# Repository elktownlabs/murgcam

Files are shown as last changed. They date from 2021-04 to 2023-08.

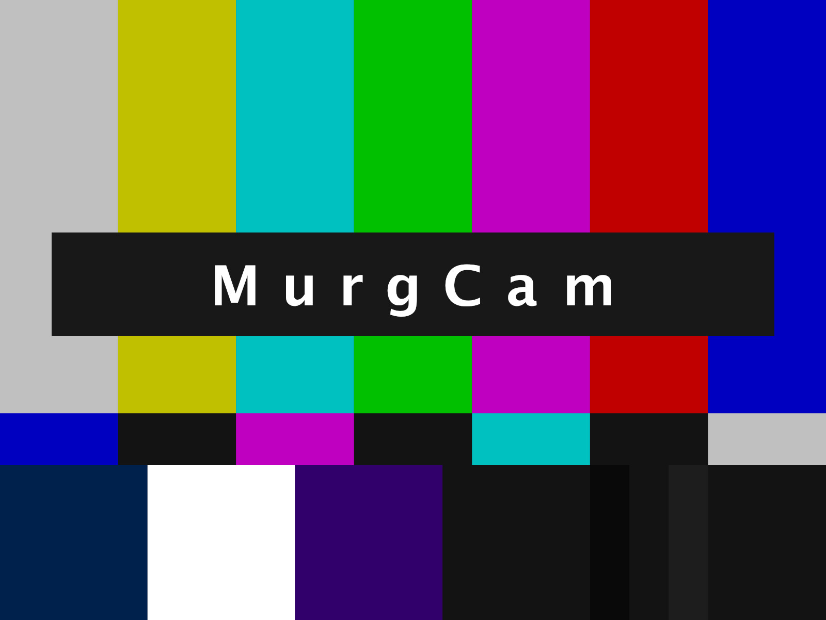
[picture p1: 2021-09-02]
web-backend/api/testcard.jpg

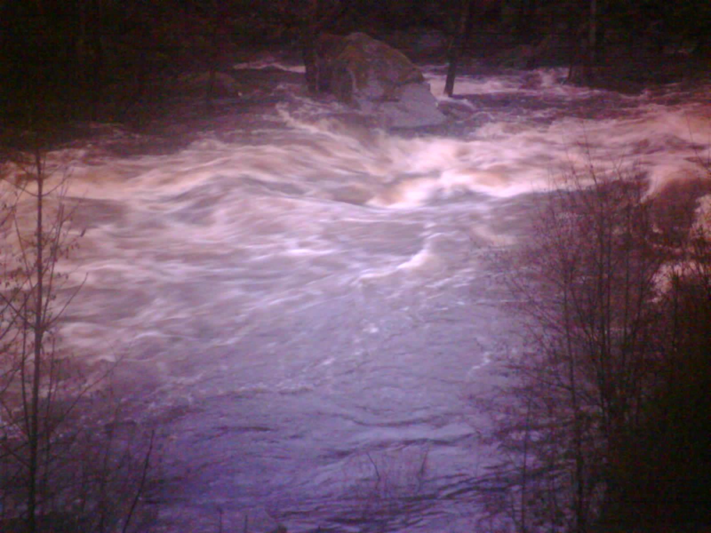
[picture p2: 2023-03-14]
web-backend/refphotos/high.jpeg

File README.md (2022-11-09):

# murgcam
Autonomous, time-based, low power still camera.

The first instance of this camera in action:
https://wwv-schwarzwald.de/die-murg/cam

## Project description
This repo documents Hard- and Software for a very low-power, battery/solar powered camera with GSM/LTE connectivity.
It is designed to operate unattended for months in an off-grid environment.
It will upload images to a server on a time-based trigger.

The intended use-case is to monitor river-waterlevels for whitewater paddlers. 
The advantage of a camera over other gauging techniques 
is, only line-of sight is needed, no access to the Water.
Being diectly at the water brings legal and mechanical challenginges that are not at play using a camera.

Full discussion of the original design decisions here:
https://elktown-labs.com/autonomouscam/

## Status
The repo just transferred from non-public to public, we try to add more documentation.
Currently, work is going on for a new hardware revision with a few improvements, most notably upgrading to a LTE capable Modem.

## Participation welcome
If you are interested in building / operating such a camera or want to contribute to it's development,
feel free to open an [issue](https://github.com/elktownlabs/murgcam/issues).

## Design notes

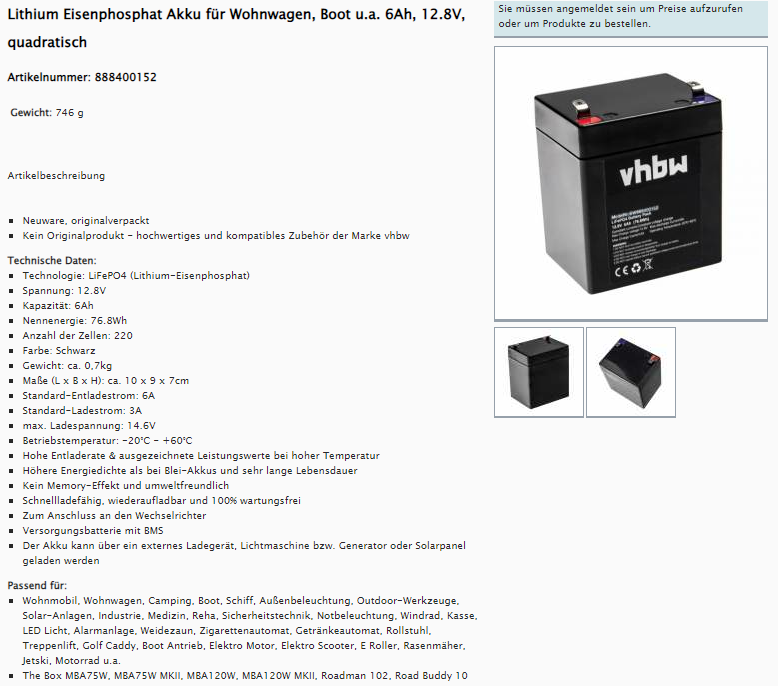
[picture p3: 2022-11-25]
cad/battery/battery_LiFePO4.png

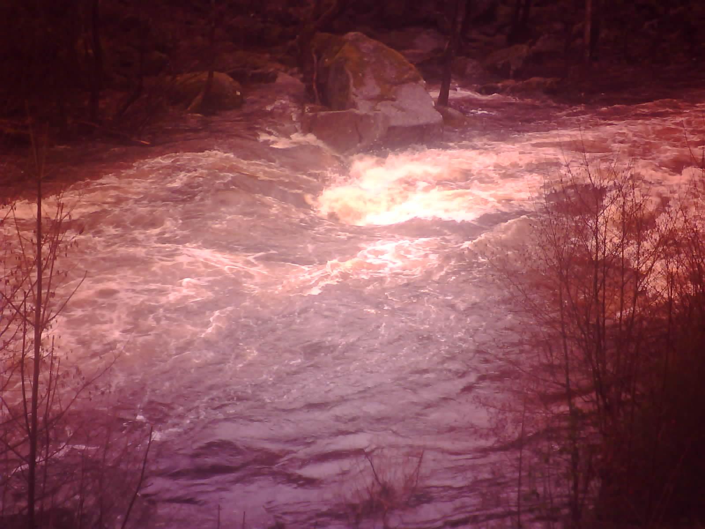
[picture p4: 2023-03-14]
web-backend/refphotos/medium.jpeg

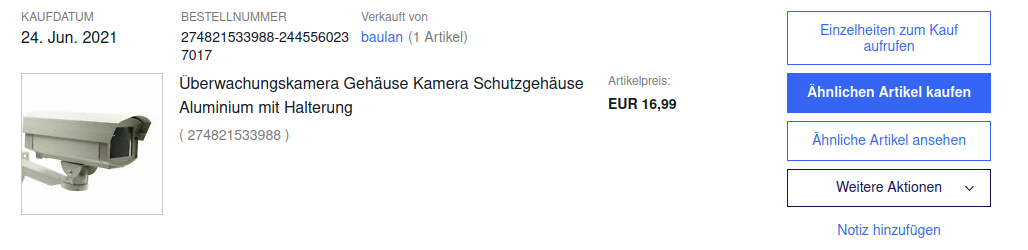
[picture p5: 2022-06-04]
cad/enclosure_narrow/cam_narrow.png

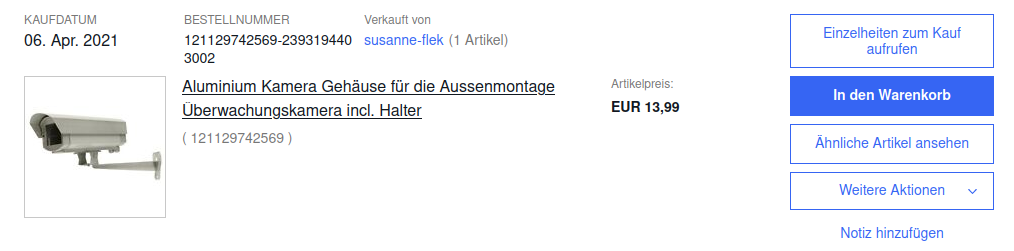
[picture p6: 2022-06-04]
cad/enclosure_wide/cam_wide.png

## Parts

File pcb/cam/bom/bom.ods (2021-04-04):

Reference | Value | Footprint
U13 | SIM800C | RF_GSM:SIMCom_SIM800C
J5 | SIM_Card | Elktown Footprints:MicroSim_6P
R20 | 51 | Resistor_SMD:R_0603_1608Metric
R21 | 51 | Resistor_SMD:R_0603_1608Metric
R22 | 51 | Resistor_SMD:R_0603_1608Metric
C43 | 100n | Capacitor_SMD:C_0603_1608Metric
C42 | 22p | Capacitor_SMD:C_0603_1608Metric
J6 | Conn_Coaxial | Connector_Coaxial:U.FL_Hirose_U.FL-R-SMT-1_Vertical
R23 | 10k | Resistor_SMD:R_0603_1608Metric
R24 | 39k | Resistor_SMD:R_0603_1608Metric
R25 | 10k | Resistor_SMD:R_0603_1608Metric
R26 | 39k | Resistor_SMD:R_0603_1608Metric
C46 | 15p | Capacitor_SMD:C_0603_1608Metric
R27 | 51 | Resistor_SMD:R_0603_1608Metric
U3 | XC6206-12 | Package_TO_SOT_SMD:SOT-23
U4 | XC6206-28 | Package_TO_SOT_SMD:SOT-23
C9 | 10u | Capacitor_SMD:C_0805_2012Metric
C16 | 10u | Capacitor_SMD:C_0805_2012Metric
C17 | 10u | Capacitor_SMD:C_0805_2012Metric
C45 | 100n | Capacitor_SMD:C_0603_1608Metric
R13 | 10k | Resistor_SMD:R_0603_1608Metric
R11 | 4.7k | Resistor_SMD:R_0603_1608Metric
J2 | Power In | Connector_JST:JST_XH_B2B-XH-A_1x02_P2.50mm_Vertical
D1 | SMAJ15CA | Diode_SMD:D_SMA
C18 | 22n | Capacitor_SMD:C_0603_1608Metric
TP1 | 1V2 | TestPoint:TestPoint_Loop_D2.60mm_Drill0.9mm_Beaded
TP2 | 2V8 | TestPoint:TestPoint_Loop_D2.60mm_Drill0.9mm_Beaded
U12 | SRV05-4 | Package_TO_SOT_SMD:SOT-23-6 | Not populated
C8 | 10u | Capacitor_SMD:C_0805_2012Metric
L2 | 10u, 3A | Elktown Footprints:IND_LPS3314-222MRC
C6 | 100n | Capacitor_SMD:C_0603_1608Metric
TP3 | 3V3 | TestPoint:TestPoint_Loop_D2.60mm_Drill0.9mm_Beaded
C19 | 22p | Capacitor_SMD:C_0603_1608Metric
R6 | 442k | Resistor_SMD:R_0603_1608Metric
C20 | 100n | Capacitor_SMD:C_0603_1608Metric
U1 | TPS22810 | Package_TO_SOT_SMD:SOT-23-6
U6 | INA226 | Package_SO:VSSOP-10_3x3mm_P0.5mm
R4 | 50mOhm 1% | Inductor_SMD:L_1206_3216Metric
U2 | FDC610 | Package_TO_SOT_SMD:SuperSOT-6
C23 | 100n | Capacitor_SMD:C_0603_1608Metric
J1 | Conn_Coaxial | Connector_Coaxial:U.FL_Hirose_U.FL-R-SMT-1_Vertical
C1 | open | Capacitor_SMD:C_0603_1608Metric
C2 | short | Capacitor_SMD:C_0603_1608Metric
L1 | open | Inductor_SMD:L_0603_1608Metric
Y2 | 40Mhz | Crystal:Crystal_SMD_5032-4Pin_5.0x3.2mm | Ordered AliExpress
C10 | TBD | Capacitor_SMD:C_0603_1608Metric
C13 | TBD | Capacitor_SMD:C_0603_1608Metric
C14 | 1u | Capacitor_SMD:C_0603_1608Metric
R5 | 0 | Inductor_SMD:L_0603_1608Metric
C28 | 100n | Capacitor_SMD:C_0603_1608Metric
C34 | 100n | Capacitor_SMD:C_0603_1608Metric
C37 | 100n | Capacitor_SMD:C_0603_1608Metric
R14 | 4.7k | Resistor_SMD:R_0603_1608Metric
U5 | LTC3103 | Package_SO:MSOP-10-1EP_3x3mm_P0.5mm_EP1.68x1.88mm
C11 | 1u, 25V CERAMIC | Capacitor_SMD:C_0805_2012Metric | Ordered AliExpress
R8 | 2M | Resistor_SMD:R_0603_1608Metric
R7 | 1M | Resistor_SMD:R_0603_1608Metric
C50 | 10p | Capacitor_SMD:C_0603_1608Metric
C49 | 33p | Capacitor_SMD:C_0603_1608Metric
C48 | 10u | Capacitor_SMD:C_0805_2012Metric | Ordered AliExpress
C44 | 100n | Capacitor_SMD:C_0603_1608Metric
Q1 | IRLML6402 | Package_TO_SOT_SMD:SOT-23
R9 | 10k | Resistor_SMD:R_0603_1608Metric
C38 | 100u, 10V | Capacitor_SMD:C_1206_3216Metric | Ordered AliExpress
C22 | 22u, 25V | Capacitor_SMD:C_1210_3225Metric
TP4 | 4V | TestPoint:TestPoint_Loop_D2.60mm_Drill0.9mm_Beaded | Ordered AliExpress
C32 | 10n | Capacitor_SMD:C_0603_1608Metric
R16 | 33.2k | Resistor_SMD:R_0603_1608Metric
R15 | 10k | Resistor_SMD:R_0603_1608Metric
R12 | 6.8k | Resistor_SMD:R_0603_1608Metric
C30 | 3.9n | Capacitor_SMD:C_0603_1608Metric | Use 3.3n
R10 | 47k | Resistor_SMD:R_0603_1608Metric
C27 | 100n | Capacitor_SMD:C_0603_1608Metric
U8 | MP2307 | Package_SO:SOIC-8-1EP_3.9x4.9mm_P1.27mm_EP2.514x3.2mm
L3 | 15u, 2.3A | Elktown Footprints:MSS7348-XXXMEC
C21 | 47u | Capacitor_SMD:C_1206_3216Metric | Ordered AliExpress
U10 | W25Q128JVS | Package_SO:SOIC-8_5.23x5.23mm_P1.27mm | Ordered AliExpress
R17 | 10k | Resistor_SMD:R_0603_1608Metric
U11 | LY68L6400 | Package_SO:SOIC-8_3.9x4.9mm_P1.27mm
R19 | TBD | Resistor_SMD:R_0603_1608Metric
D2 | LED_RED | LED_SMD:LED_0603_1608Metric
R18 | TBD | Resistor_SMD:R_0603_1608Metric
D3 | LED_BLUE | LED_SMD:LED_0603_1608Metric
C5 | 10u, 25V ceramic | Capacitor_SMD:C_1210_3225Metric | Schublade
C41 | 100n | Capacitor_SMD:C_0603_1608Metric
C40 | 100n | Capacitor_SMD:C_0603_1608Metric
J4 | Conn_01x24_Male | Connector_FFC-FPC:Hirose_FH12-24S-0.5SH_1x24-1MP_P0.50mm_Horizontal
R3 | open | Resistor_SMD:R_0603_1608Metric
C29 | 10u | Capacitor_SMD:C_0805_2012Metric | Ordered AliExpress
C33 | 100n | Capacitor_SMD:C_0603_1608Metric
C25 | 100n | Capacitor_SMD:C_0603_1608Metric
C26 | 100n | Capacitor_SMD:C_0603_1608Metric
C7 | TBD | Capacitor_SMD:C_0603_1608Metric
Y1 | 32.768kHz | Crystal:Crystal_SMD_SeikoEpson_MC306-4Pin_8.0x3.2mm
C12 | TBD | Capacitor_SMD:C_0603_1608Metric
C15 | 1u | Capacitor_SMD:C_0603_1608Metric
R1 | 0 | Resistor_SMD:R_0603_1608Metric
R28 | 0 | Resistor_SMD:R_0603_1608Metric
R29 | 10k | Resistor_SMD:R_0603_1608Metric
R31 | 4.7k | Resistor_SMD:R_0603_1608Metric
R30 | 4.7k | Resistor_SMD:R_0603_1608Metric
R32 | 10k | Resistor_SMD:R_0603_1608Metric
J7 | JTAG | Connector_PinHeader_1.27mm:PinHeader_2x05_P1.27mm_Vertical | Ordered AliExpress: does not fit. Need to be re-ordered
J3 | PRGR | Connector_PinHeader_1.27mm:PinHeader_2x03_P1.27mm_Vertical
C39 | 100n | Capacitor_SMD:C_0603_1608Metric
R2 | 10k | Resistor_SMD:R_0603_1608Metric
C3 | 100p | Capacitor_SMD:C_0603_1608Metric
C4 | 1u | Capacitor_SMD:C_0603_1608Metric
U7 | ESP32-S2 | Package_DFN_QFN:QFN-56-1EP_7x7mm_P0.4mm_EP5.6x5.6mm_ThermalVias | Ordered AliExpress

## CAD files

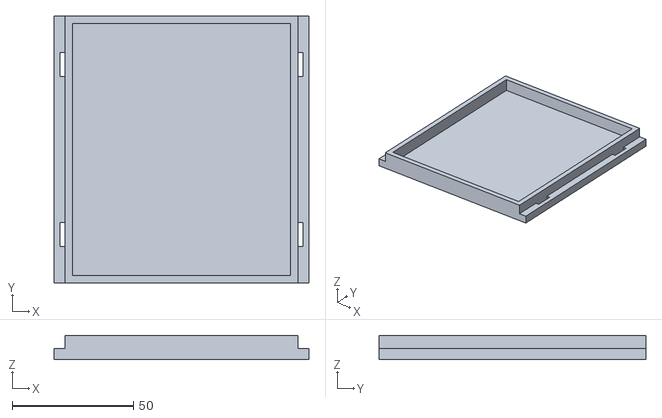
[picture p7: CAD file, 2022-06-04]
cad/enclosure_wide/base_for_battery/base.stl
105.0 x 110.0 x 10.0

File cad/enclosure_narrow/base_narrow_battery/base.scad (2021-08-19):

WIDTH = 98.0;
LENGTH = 111;
HEIGHT = 3.5;
HOLDER_HEIGHT = 1.7;
BORDER_HEIGHT = 13;
HOLDER_WIDTH = 5.5;
BORDER_WIDTH=0;
BORDER_WIDTH_FRONTBACK = 4;

union() {
    cube([WIDTH, LENGTH, HOLDER_HEIGHT]);
    translate([HOLDER_WIDTH, 0, HOLDER_HEIGHT/2])
        difference() {
            cube([WIDTH - (2*HOLDER_WIDTH), LENGTH, BORDER_HEIGHT]);
            translate([BORDER_WIDTH, BORDER_WIDTH_FRONTBACK, HEIGHT]) 
                cube([WIDTH - (2*(HOLDER_WIDTH+BORDER_WIDTH)), LENGTH-(2*BORDER_WIDTH_FRONTBACK), BORDER_HEIGHT-HEIGHT]);
        }
    translate([0, WIDTH/2+5, 0]) linear_extrude(height=HOLDER_HEIGHT) circle(r=10);
}

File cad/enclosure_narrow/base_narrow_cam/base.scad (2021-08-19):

include <bolts/BOLTS.scad>
$fn=30;

WIDTH = 98.0;
LENGTH = 75;
HEIGHT=3.5;
HOLDER_HEIGHT = 1.7;
HOLDER_WIDTH = 5.5;


BOARD_HOLE_WIDTH=55;
BOARD_HOLE_LENGTH=65;
BOARD_MOUNTING_HEIGHT=5;

module board_holder(height) {
    union() {
        difference() {
            cube([10, 10, height]);
            translate([5, 5, -0.5]) {
                cylinder(height+1, d=3.2);
                cylinder(height, d=3.4);
            }
            translate([5, 5, -0.01]) 
            scale([1.1, 1.1, 1])
                ISO4032("M3",part_mode="diff");    
        }
    }
}


union() {

    difference() {
        union() {
            cube([WIDTH, LENGTH, HOLDER_HEIGHT]);
            translate([HOLDER_WIDTH, 0, HOLDER_HEIGHT/2])
            cube([WIDTH - (2*HOLDER_WIDTH), LENGTH, HEIGHT]);
        }
        translate([(WIDTH-BOARD_HOLE_WIDTH-10)/2, 0, 0]) {
            translate([0, 0, -0.05])
            cube(10, 10, BOARD_MOUNTING_HEIGHT+HEIGHT+0.1);
            translate([BOARD_HOLE_WIDTH, 0, -0.05])
            cube(10, 10, BOARD_MOUNTING_HEIGHT+HEIGHT+0.1);
            translate([0, BOARD_HOLE_LENGTH, -0.05])
            cube(10, 10, BOARD_MOUNTING_HEIGHT+HEIGHT+0.1);
            translate([BOARD_HOLE_WIDTH, BOARD_HOLE_LENGTH, -0.05])
            cube(10, 10, BOARD_MOUNTING_HEIGHT+HEIGHT+0.1);
        }
        
        translate([(WIDTH-BOARD_HOLE_WIDTH-9.5)/2 - 6, 30, -0.1]) {
            cylinder(10, d=3.2);            
        }
        translate([WIDTH-((WIDTH-BOARD_HOLE_WIDTH-9.5)/2 - 6), 30, -0.1]) {
            cylinder(10, d=3.2);            
        }
        translate([(WIDTH-BOARD_HOLE_WIDTH-9.5)/2 - 6, 40, -0.1]) {
            cylinder(10, d=3.2);            
        }
        translate([WIDTH-((WIDTH-BOARD_HOLE_WIDTH-9.5)/2 - 6), 40, -0.1]) {
            cylinder(10, d=3.2);            
        }
        translate([(WIDTH-BOARD_HOLE_WIDTH-9.5)/2 - 6, 50, -0.1]) {
            cylinder(10, d=3.2);            
        }
        translate([WIDTH-((WIDTH-BOARD_HOLE_WIDTH-9.5)/2 - 6), 50, -0.1]) {
            cylinder(10, d=3.2);            
        }
        translate([(WIDTH-BOARD_HOLE_WIDTH-9.5)/2 - 6, 60, -0.1]) {
            cylinder(10, d=3.2);            
        }
        translate([WIDTH-((WIDTH-BOARD_HOLE_WIDTH-9.5)/2 - 6), 60, -0.1]) {
            cylinder(10, d=3.2);            
        }

    }
                
    translate([(WIDTH-BOARD_HOLE_WIDTH-10)/2, 0, 0]) {
        translate([0, 0, -0.05])
        board_holder(BOARD_MOUNTING_HEIGHT+HEIGHT+0.1);
        translate([BOARD_HOLE_WIDTH, 0, -0.05])
        board_holder(BOARD_MOUNTING_HEIGHT+HEIGHT+0.1);
        translate([0, BOARD_HOLE_LENGTH, -0.05])
        board_holder(BOARD_MOUNTING_HEIGHT+HEIGHT+0.1);
        translate([BOARD_HOLE_WIDTH, BOARD_HOLE_LENGTH, -0.05])
        board_holder(BOARD_MOUNTING_HEIGHT+HEIGHT+0.1);
    }
}

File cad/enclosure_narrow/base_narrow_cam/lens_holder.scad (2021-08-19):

include <bolts/BOLTS.scad>

$fn=30;

BOARD_HOLE_WIDTH=55;
COLUMN_WIDTH=9.5;
HEIGHT=40;

DIST = BOARD_HOLE_WIDTH+(2*COLUMN_WIDTH)+2;

// left left
difference() {
    union() {
        cube([COLUMN_WIDTH, 10, HEIGHT]);
        translate([(COLUMN_WIDTH-15)/2, 0, 14])
        cube([15, 10, 12]);
    }
    rotate([-90, 0, 0])
        translate([4.8, -20, -0.1]) {
            scale([1.1, 1.1, 1.6])
            ISO4032("M5",part_mode="diff");    
            cylinder(h=45, d=6.6);
        }

    translate([COLUMN_WIDTH/2, 5, 0])
    cylinder(h=15, d=3.2);
    translate([COLUMN_WIDTH/2-(5.7/2), (10-5.7)/2-3, 3])
    cube([5.7, 8.7, 2.6]);


}

// right leg
translate([DIST, 0, 0])
difference() {
    cube([COLUMN_WIDTH, 10, HEIGHT]);
    translate([COLUMN_WIDTH/2, 5, 0])
    cylinder(h=15, d=3.2);
    translate([COLUMN_WIDTH/2-(5.7/2), (10-5.7)/2-3, 3])
    cube([5.7, 8.7, 2.6]);
}

difference() {
    union() {
        translate([0, 0, HEIGHT-10])
        cube([DIST+COLUMN_WIDTH, 10, 10]);
        translate([(DIST+COLUMN_WIDTH-18)/2, 0, HEIGHT-10-4]) 
        cube([18, 10, 18]);
    }
    
    
    // ccd slot
    translate([(DIST+COLUMN_WIDTH-9.2)/2, 0, HEIGHT-9.2-((10-9.2)/2)]) {
        cube([9.2, 1.2, 9.2]);
    }
    translate([(DIST+COLUMN_WIDTH-6.2)/2, 0, 28.5]) {
        cube([6.2, 1.2, 9.2]);
    }   
   
   // mounting holes
   translate([(DIST+COLUMN_WIDTH)/2-10, 10, (HEIGHT-5)])
   rotate([90, 0, 0])
   cylinder(d=2.7, h=10); 
   translate([(DIST+COLUMN_WIDTH)/2+10, 10, (HEIGHT-5)])
   rotate([90, 0, 0])
   cylinder(d=2.7, h=10); 
    
    // mounting holes for screw heads
   translate([(DIST+COLUMN_WIDTH)/2-10, 10, (HEIGHT-5)])
   rotate([90, 0, 0])
   cylinder(d=5.5, h=6); 
   translate([(DIST+COLUMN_WIDTH)/2+10, 10, (HEIGHT-5)])
   rotate([90, 0, 0])
   cylinder(d=5.5, h=6); 

}

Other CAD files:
cad/enclosure_wide/base_for_battery/base.scad
cad/enclosure_narrow/base_narrow_cam/bolts/BOLTS.scad
cad/enclosure_narrow/base_narrow_cam/bolts/BOLTS_ANSI.scad
cad/enclosure_narrow/base_narrow_cam/bolts/BOLTS_ASME.scad
cad/enclosure_narrow/base_narrow_cam/bolts/BOLTS_DIN.scad
cad/enclosure_narrow/base_narrow_cam/bolts/BOLTS_DINEN.scad
cad/enclosure_narrow/base_narrow_cam/bolts/BOLTS_DINENISO.scad
cad/enclosure_narrow/base_narrow_cam/bolts/BOLTS_DINISO.scad
cad/enclosure_narrow/base_narrow_cam/bolts/BOLTS_EN.scad
cad/enclosure_narrow/base_narrow_cam/bolts/BOLTS_ISO.scad
cad/enclosure_narrow/base_narrow_cam/bolts/base/aluminiumProfiles.scad
cad/enclosure_narrow/base_narrow_cam/bolts/base/batteries.scad
cad/enclosure_narrow/base_narrow_cam/bolts/base/bearings.scad
cad/enclosure_narrow/base_narrow_cam/bolts/base/hex.scad
cad/enclosure_narrow/base_narrow_cam/bolts/base/hex_socket.scad
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

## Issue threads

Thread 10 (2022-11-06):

Überlegen ob es möglich und vorteilhaft wäre auf Raspi-Kameramodule zu wechseln

sirtet, 2022-11-06:
Scheint auf den ersten Blick um CSI Camera Serial Interface zu gehen in beiden Fällen.
Wenn gewisse Raspi Kameramodule kompatibel wäre, wäre es mechanisch einfacher dafür Linsen und Halterungen zu bekommen.
die seltenen 1.2V und 2.8V Regler wären schon auf der Kamera-Platine, müssten nicht am Mainboard sein.

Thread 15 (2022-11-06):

Empfohlenes Vorgehen für manuellen PCB Aufbau dokumentieren

sirtet, 2022-11-06:
In readme oder so.
Mein Vorgehen (teils notiert teils erinnert):

1. ESP, quarz und seine c’s, R5 löten
 test 1:
 3v3 extern anlegen über TP 3v3
 XTAL_P und _N schwingen nicht… hmm, ist ev. GND nicht gelötet? Scheint untestbar... das Center-Pad ist die einzige GND Verbindung.
 Hmm... braucht es einen sauberen Reset? Mal probieren: R2, C39 löten
  aha, XTAL_P und _N schwingen mit 40mhz ~1Vpp
test 2:
3v3 von Labornetzteil anlegen und an TX schauen ob der Bootloader text ausgibt

2. RAM + ROM einlöten
 testen:
 Firmware flashen, siehe...xxx

3. U5 Vreg. 3V3
passende r fehlen:
R8 2M >> 3M3 || 4M7 = 1M95
R6 430K >> 4M7 || 470K = 427K [hier berechnet](https://www.inventable.eu/parallel-resistors-calculator/)
Das gibt Vout von 3.340V statt 3.390V
testen:
5V mit Strombegrenzung auf wenige mA an VSUPPLY legen, 3v3 messen.

4. Spannungsschutz / Spannungsmessung U2, U6 & co. löten
 testen:
 Bootloader Output

5. U8 etc. best.
testen:
RADIO_EN auf GND legen, 4V messen, Bootloader-Output

6. Modem & Co., LED’s, WLAN & co. bestückt
WLAN Test: während Beim Booten die blaue LED brennt, strom aus, wieder an (ginge wohl auch reset?).
Danach startet WLAN Hotspot, (LED blinkt, gui auf 192.168.4.1)

7.
gesamter Rest bestücken

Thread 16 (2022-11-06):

readme.md anlegen

sirtet, 2022-11-06:
Projekt-Ziel und grobe Funktion erklären.
(kann wohl teilweise aus blogpost extrahiert werden?)

kann man mal hier beginnen zu schreiben...
A ultra- low power battery operated "webcam" with wireless connection.
Intended use:
River-waterlevel observation.

target parameters:
battery- or solar-power
LTE Uplink

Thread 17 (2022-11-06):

Board schon flashen wenn man erst den ESP bestückt hat?

sirtet, 2022-11-06:
Für den manuellen Aufbau:
Es ist sinnvoll die MCU schon vor möglichen folgenden Bestückungsfehlern zu testen.
Das heisst 3v3 anhängen und auf UART schauen ob die Bootloader-textausgabe kommt.
Kurz darauf kann/will man auch die Firmware flashen (braucht dann aber auch das Flash IC)
Dazu ist momentan der PRG Header nötig, der Through-hole ist.
Aber wenn man den schon bestückt, wird die folgende SMD Arbeit mühsamer, da PCB Unterseite nicht mehr plan am Tisch aufliegen kann.
Ideen:

- PRG Header als SMD? Mechanisch weniger stabil denke ich...
- PRG header SMD einreihig liegend? Flacher macht weiteres Bestücken einfacher...
- TP's anlegen wo man optional die nötigen Drähte leicht direkt anlöten kann?
Dann auch GND- Lötbrücke für GPIO 0 ergänzen

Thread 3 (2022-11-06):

Programmierheader auch mit 0.1" ausführen

sirtet, 2022-11-06:
Der verwendete 1.27mm ist arg klein und unüblich für Bastler.
Ist genug Platz da für zusätzlich Bohrungen in 2.54mm.

Am besten auch gleich mit 8 statt 6 pins, 2 extra GND gegenüber RST und PRG, damit man die mit Jumpern setzen kann...

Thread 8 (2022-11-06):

zusätzliche 0R Brücken zum testen

sirtet, 2022-11-06:
1. Brücke nach dem Ausgang von U5
damit man den Regler zu Testzwecken vom Rest der Schaltung abtrennen kann.

2. Brücke zu GND an Gate Q1, so dass man den 4V Regler zum testen aktivieren kann
(4V wird im Betrieb nur per software aktiviert wenn modem laufen muss)

Diese und alle schon vorhandenen 0R Brücken: Kann man die Lötpads ev. mit weniger Abstand ausführen, dass sie leichter ohne Bauteil, nur mit Zinn überbrückbar sind?

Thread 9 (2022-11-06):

Stromversorgung besser dokumentieren

sirtet, 2022-11-06:
Im Silkscreen steht Vin 5-12V?
Firmware meldet beim Boot “we need at least 10’000mV to continue”)...
Max. 12V? Wenn man einen 12V Akku lädt, hat man nicht teils etwas höhere Spannungen? Ist 12V tatsächlich max. Rating der Spannungsregler?
(wie) sind wir abgesichert gegen Überspannung?

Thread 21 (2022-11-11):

elkcam macht einen Reset wenn man versucht sich mit dem Wifi zu verbinden

sirtet, 2022-11-11:
Die Kamera öffnet einen wifi Hotspot namens elkcam für Zugang zum Config UI, wenn man während dem Boot die Spannungsversorgung unterbricht, während zum ersten Mal die blaue LED aufleuchtet.

Problem:
elkcam macht einen Reset, so bald versucht wird, sich mit dem Wifi der cam zu verbinden.

Lösung:
Labor- Netzteil war zu stark strombegrenzt...
Es war für erste Tests auf 12V 100mA, eingestellt, das führte zu Brownout, Wifi zieht viel Strom.
Strombegrenzung auf 500mA erhöhen löste das Problem.

Closed 2022-11-11.

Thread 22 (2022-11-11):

Kameraaufnahme schlägt fehl

sirtet, 2022-11-11:
Worauf deuten die Schreibfehler hin?

Bild per web UI angefordert, console Output:
```
I (365594) httpserver: Host 192.168.4.1 requested a picture.
I (365594) httpserver: Taking picture
I (365594) camhandler: Reinitializing cam
E (365794) sccb: SCCB_Write Failed addr:0x30, reg:0xff, data:0x01, ret:-1
E (365814) sccb: SCCB_Write Failed addr:0x30, reg:0x12, data:0x80, ret:-1
I (365934) OV2640: MID:65535
E (365934) camhandler: sensor initialization failed.
E (365944) sccb: SCCB_Write Failed addr:0x30, reg:0xff, data:0x00, ret:-1
E (365944) sccb: SCCB_Write Failed addr:0x30, reg:0xda, data:0x10, ret:-1
E (365954) sccb: SCCB_Write Failed addr:0x30, reg:0xd7, data:0x03, ret:-1
E (365964) sccb: SCCB_Write Failed addr:0x30, reg:0xdf, data:0x00, ret:-1
E (365974) sccb: SCCB_Write Failed addr:0x30, reg:0x33, data:0x80, ret:-1
E (365984) sccb: SCCB_Write Failed addr:0x30, reg:0x3c, data:0x40, ret:-1
E (365994) sccb: SCCB_Write Failed addr:0x30, reg:0xe1, data:0x77, ret:-1
E (366004) sccb: SCCB_Write Failed addr:0x30, reg:0x00, data:0x00, ret:-1
E (366004) sccb: SCCB_Write Failed addr:0x30, reg:0xff, data:0x00, ret:-1
E (366024) sccb: SCCB_Write Failed addr:0x30, reg:0xda, data:0xff, ret:-1
E (366034) sccb: SCCB_Write Failed addr:0x30, reg:0xff, data:0x01, ret:-1
E (366044) sccb: SCCB_Write Failed addr:0x30, reg:0xe0, data:0x14, ret:-1
E (366044) sccb: SCCB_Write Failed addr:0x30, reg:0xe1, data:0x77, ret:-1
E (366054) sccb: SCCB_Write Failed addr:0x30, reg:0xe5, data:0x1f, ret:-1
E (366064) sccb: SCCB_Write Failed addr:0x30, reg:0xd7, data:0x03, ret:-1
E (366064) sccb: SCCB_Write Failed addr:0x30, reg:0xda, data:0x10, ret:-1
E (366084) sccb: SCCB_Write Failed addr:0x30, reg:0xe0, data:0x00, ret:-1
E (366094) sccb: SCCB_Write Failed addr:0x30, reg:0x44, data:0x0a, ret:-1
E (366104) sccb: SCCB_Write Failed addr:0x30, reg:0xff, data:0x00, ret:-1
E (366104) sccb: SCCB_Write Failed addr:0x30, reg:0xe0, data:0x04, ret:-1
E (366114) sccb: SCCB_Write Failed addr:0x30, reg:0xc0, data:0xc8, ret:-1
E (366124) sccb: SCCB_Write Failed addr:0x30, reg:0xc1, data:0x96, ret:-1
E (366134) sccb: SCCB_Write Failed addr:0x30, reg:0x8c, data:0x00, ret:-1
E (366144) sccb: SCCB_Write Failed addr:0x30, reg:0xe0, data:0x00, ret:-1
E (366154) sccb: SCCB_Write Failed addr:0x30, reg:0xff, data:0x00, ret:-1
E (366164) sccb: SCCB_Write Failed addr:0x30, reg:0xe0, data:0x04, ret:-1
E (366174) sccb: SCCB_Write Failed addr:0x30, reg:0x51, data:0x90, ret:-1
E (366184) sccb: SCCB_Write Failed addr:0x30, reg:0x52, data:0x2c, ret:-1
E (366194) sccb: SCCB_Write Failed addr:0x30, reg:0x53, data:0x00, ret:-1
E (366204) sccb: SCCB_Write Failed addr:0x30, reg:0x54, data:0x00, ret:-1
E (366204) sccb: SCCB_Write Failed addr:0x30, reg:0x55, data:0x88, ret:-1
E (366224) sccb: SCCB_Write Failed addr:0x30, reg:0x57, data:0x00, ret:-1
E (366234) sccb: SCCB_Write Failed addr:0x30, reg:0xe0, data:0x00, ret:-1
E (366244) sccb: SCCB_Write Failed addr:0x30, reg:0xff, data:0x00, ret:-1
E (366254) sccb: SCCB_Write Failed addr:0x30, reg:0xe0, data:0x04, ret:-1
E (366264) sccb: SCCB_Write Failed addr:0x30, reg:0x5a, data:0x90, ret:-1
E (366264) sccb: SCCB_Write Failed addr:0x30, reg:0x5b, data:0x2c, ret:-1
E (366274) sccb: SCCB_Write Failed addr:0x30, reg:0x5c, data:0x05, ret:-1
E (366284) sccb: SCCB_Write Failed addr:0x30, reg:0xe0, data:0x00, ret:-1
I (366284) camhandler: Configuring camera to global config settings
E (366294) sccb: SCCB_Write Failed addr:0x30, reg:0xff, data:0x01, ret:-1
E (366314) sccb: SCCB_Write Failed addr:0x30, reg:0x11, data:0xff, ret:-1
I (366314) camhandler: Setting pixel timing to 0
E (366324) sccb: SCCB_Write Failed addr:0x30, reg:0xff, data:0x00, ret:-1
E (366334) sccb: SCCB_Write Failed addr:0x30, reg:0x44, data:0x0a, ret:-1
I (366334) camhandler: Setting picture quality to 10
E (366344) sccb: SCCB_Write Failed addr:0x30, reg:0xff, data:0x01, ret:-1
E (366354) sccb: SCCB_Write Failed addr:0x30, reg:0x24, data:0x3e, ret:-1
E (366364) sccb: SCCB_Write Failed addr:0x30, reg:0x25, data:0x38, ret:-1
E (366374) sccb: SCCB_Write Failed addr:0x30, reg:0x26, data:0x81, ret:-1
I (366374) camhandler: Setting auto exposure to 2
E (366374) sccb: SCCB_Write Failed addr:0x30, reg:0xff, data:0x00, ret:-1
E (366394) sccb: SCCB_Write Failed addr:0x30, reg:0xc7, data:0x00, ret:-1
I (366394) camhandler: Setting light mode to 0
E (366404) sccb: SCCB_Write Failed addr:0x30, reg:0xff, data:0x00, ret:-1
I (366404) OV2640: Set 255 to 0
E (366414) sccb: SCCB_Write Failed addr:0x30, reg:0x7c, data:0x00, ret:-1
I (366414) OV2640: Set 124 to 0
E (366434) sccb: SCCB_Write Failed addr:0x30, reg:0x7d, data:0xfd, ret:-1
I (366434) OV2640: Set 125 to 253
I (366434) camhandler: Setting color saturation to 0
E (366454) sccb: SCCB_Write Failed addr:0x30, reg:0xff, data:0x00, ret:-1
I (366454) OV2640: Set 255 to 0
E (366464) sccb: SCCB_Write Failed addr:0x30, reg:0x7c, data:0x00, ret:-1
I (366464) OV2640: Set 124 to 0
E (366484) sccb: SCCB_Write Failed addr:0x30, reg:0x7d, data:0xfb, ret:-1
I (366484) OV2640: Set 125 to 251
I (366484) camhandler: Setting brightness to 0
E (366494) sccb: SCCB_Write Failed addr:0x30, reg:0xff, data:0x00, ret:-1
I (366494) OV2640: Set 255 to 0
E (366514) sccb: SCCB_Write Failed addr:0x30, reg:0x7c, data:0x00, ret:-1
I (366514) OV2640: Set 124 to 0
E (366524) sccb: SCCB_Write Failed addr:0x30, reg:0x7d, data:0xfb, ret:-1
I (366524) OV2640: Set 125 to 251
I (366524) camhandler: Setting contrast to 0
E (366544) sccb: SCCB_Write Failed addr:0x30, reg:0xff, data:0x00, ret:-1
I (366544) OV2640: Set 255 to 0
E (366554) sccb: SCCB_Write Failed addr:0x30, reg:0x7c, data:0x00, ret:-1
I (366554) OV2640: Set 124 to 0
E (366574) sccb: SCCB_Write Failed addr:0x30, reg:0x7d, data:0xfe, ret:-1
I (366574) OV2640: Set 125 to 254
I (366574) camhandler: Setting hue to 0
E (366574) sccb: SCCB_Write Failed addr:0x30, reg:0xff, data:0x00, ret:-1
I (366584) OV2640: Set 255 to 0
E (366594) sccb: SCCB_Write Failed addr:0x30, reg:0x92, data:0x01, ret:-1
I (366594) OV2640: Set 146 to 1
E (366614) sccb: SCCB_Write Failed addr:0x30, reg:0x93, data:0xff, ret:-1
I (366614) OV2640: Set 147 to 255
I (366614) camhandler: Setting sharpness to 0
E (366634) sccb: SCCB_Write Failed addr:0x30, reg:0xff, data:0x01, ret:-1
E (366654) sccb: SCCB_Write Failed addr:0x30, reg:0x04, data:0x7f, ret:-1
I (366654) camhandler: Setting flip/mirror to 0
I (366654) camhandler: Waiting for camera to settle
E (378654) httpserver: Camera timed out

```
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

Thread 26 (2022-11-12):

Modem scheint nicht richtig zu antworten

sirtet, 2022-11-12:
```
I (12844) main: Uploading picture to server
I (12854) main: Power down modem for 2s
I (14854) main: Power up modem
I (15354) main: Power key on for 1.2s
I (16554) main: Power key off and wait 1s
I (17554) main: Init modem
I (17554) cellmodem: Init DTE
I (17554) uart: queue free spaces: 30
I (17554) cellmodem: Init SIM800
I (17554) esp-modem: Sending command: AT
E (18054) esp-modem: esp_modem_dte_send_cmd(231): process command timeout
E (18054) dce_service: esp_modem_dce_sync(48): send command failed
E (18054) sim800: sim800_init(656): sync failed
I (18054) cellmodem: Modem not yet initialized.
I (19064) esp-modem: Sending command: AT
I (19064) esp-modem: Line received: ▒▒AT
 (ff ff)
I (19114) esp-modem: Line received: OK
 (4f 4b)
I (19114) esp-modem: Sending command: ATE0
I (19164) esp-modem: Line received: ATE0
 (41 54)
E (19164) esp-modem: esp_dte_handle_line(92): handle line failed
W (19164) cellmodem: Unknown line received: ATE0
 (41 54 45 30 d d)
I (19214) esp-modem: Line received: OK
 (4f 4b)
I (19214) esp-modem: Sending command: AT+CGMM
I (19264) esp-modem: Line received:
 (d a)
I (19314) esp-modem: Line received: SIMCOM_SIM800C
 (53 49)
I (19364) esp-modem: Line received:
 (d a)
I (19414) esp-modem: Line received: OK
 (4f 4b)
I (19414) esp-modem: Sending command: AT+CGSN
I (19464) esp-modem: Line received:
 (d a)
I (19514) esp-modem: Line received: +CPIN: READY
 (2b 43)
I (19564) esp-modem: Line received:
 (d a)
I (19614) esp-modem: Line received: 865532044865174
 (38 36)
I (19664) esp-modem: Line received:
 (d a)
I (19714) esp-modem: Line received: OK
 (4f 4b)
I (19714) esp-modem: Sending command: AT+CPIN?
I (19764) esp-modem: Line received:
 (d a)
I (19814) esp-modem: Line received: +CPIN: READY
 (2b 43)
I (19864) esp-modem: Line received:
 (d a)
I (19914) esp-modem: Line received: OK
 (4f 4b)
I (19914) esp-modem: Sending command: AT+CREG?
I (19964) esp-modem: Line received:
 (d a)
I (20014) esp-modem: Line received: +CREG: 0,2
 (2b 43)
I (20064) esp-modem: Line received:
 (d a)
I (20114) esp-modem: Line received: OK
 (4f 4b)
E (20114) sim800: sim800_wait_registration(524): waiting for network registration failed
E (20114) sim800: sim800_init(670): waiting for registration timed out
I (20124) cellmodem: Modem not yet initialized.
I (21124) esp-modem: Sending command: AT
I (21124) esp-modem: Line received:
 (d a)
I (21174) esp-modem: Line received: OK
 (4f 4b)
I (21174) esp-modem: Sending command: ATE0
I (21224) esp-modem: Line received:
 (d a)
I (21274) esp-modem: Line received: OK
 (4f 4b)
I (21274) esp-modem: Sending command: AT+CGMM
I (21324) esp-modem: Line received:
 (d a)
I (21374) esp-modem: Line received: SIMCOM_SIM800C
 (53 49)
I (21424) esp-modem: Line received:
 (d a)
I (21474) esp-modem: Line received: OK
 (4f 4b)
I (21474) esp-modem: Sending command: AT+CGSN
I (21524) esp-modem: Line received:
 (d a)
I (21574) esp-modem: Line received: 865532044865174
 (38 36)
I (21624) esp-modem: Line received:
 (d a)
I (21674) esp-modem: Line received: OK
 (4f 4b)
I (21674) esp-modem: Sending command: AT+CPIN?
I (21724) esp-modem: Line received:
 (d a)
I (21774) esp-modem: Line received: +CPIN: READY
 (2b 43)
I (21824) esp-modem: Line received:
 (d a)
I (21874) esp-modem: Line received: OK
 (4f 4b)
I (21874) esp-modem: Sending command: AT+CREG?
I (21924) esp-modem: Line received:
 (d a)
I (21974) esp-modem: Line received: +CREG: 0,2
 (2b 43)
I (22024) esp-modem: Line received:
 (d a)
I (22074) esp-modem: Line received: OK
 (4f 4b)
E (22074) sim800: sim800_wait_registration(524): waiting for network registration failed
E (22074) sim800: sim800_init(670): waiting for registration timed out
I (22084) cellmodem: Modem not yet initialized.
I (22494) esp-modem: Line received:
 (d a)
I (22544) esp-modem: Line received: Call Ready
 (43 61)
E (22544) esp-modem: esp_dte_handle_line(91): no handler for line
W (22544) cellmodem: Unknown line received: Call Ready
 (43 61 6c 6c 20 52)
I (23084) esp-modem: Sending command: AT
I (23084) esp-modem: Line received:
 (d a)
I (23134) esp-modem: Line received: OK
 (4f 4b)
I (23134) esp-modem: Sending command: ATE0
I (23184) esp-modem: Line received:
 (d a)
I (23234) esp-modem: Line received: OK
 (4f 4b)
I (23234) esp-modem: Sending command: AT+CGMM
I (23284) esp-modem: Line received:
 (d a)
I (23334) esp-modem: Line received: SIMCOM_SIM800C
 (53 49)
I (23384) esp-modem: Line received:
 (d a)
I (23434) esp-modem: Line received: OK
 (4f 4b)
I (23434) esp-modem: Sending command: AT+CGSN
I (23484) esp-modem: Line received:
 (d a)
I (23534) esp-modem: Line received: SMS Ready
 (53 4d)
I (23584) esp-modem: Line received:
 (d a)
I (23634) esp-modem: Line received: 865532044865174
 (38 36)
I (23684) esp-modem: Line received:
 (d a)
I (23734) esp-modem: Line received: OK
 (4f 4b)
I (23734) esp-modem: Sending command: AT+CPIN?
I (23784) esp-modem: Line received:
 (d a)
I (23834) esp-modem: Line received: +CPIN: READY
 (2b 43)
I (23884) esp-modem: Line received:
 (d a)
I (23934) esp-modem: Line received: OK
 (4f 4b)
I (23934) esp-modem: Sending command: AT+CREG?
I (23984) esp-modem: Line received:
 (d a)
I (24034) esp-modem: Line received: +CREG: 0,3
 (2b 43)
I (24084) esp-modem: Line received:
 (d a)
I (24134) esp-modem: Line received: OK
 (4f 4b)
E (24134) sim800: sim800_wait_registration(524): waiting for network registration failed
E (24134) sim800: sim800_init(670): waiting for registration timed out
I (24144) cellmodem: Modem not yet initialized.
I (25144) esp-modem: Sending command: AT
I (25144) esp-modem: Line received:
 (d a)
I (25194) esp-modem: Line received: OK
 (4f 4b)
I (25194) esp-modem: Sending command: ATE0
I (25244) esp-modem: Line received:
 (d a)
I (25294) esp-modem: Line received: OK
 (4f 4b)
I (25294) esp-modem: Sending command: AT+CGMM
I (25344) esp-modem: Line received:
 (d a)
I (25394) esp-modem: Line received: SIMCOM_SIM800C
 (53 49)
I (25444) esp-modem: Line received:
 (d a)
I (25494) esp-modem: Line received: OK
 (4f 4b)
I (25494) esp-modem: Sending command: AT+CGSN
I (25544) esp-modem: Line received:
 (d a)
I (25594) esp-modem: Line received: 865532044865174
 (38 36)
I (25644) esp-modem: Line received:
 (d a)
I (25694) esp-modem: Line received: OK
 (4f 4b)
I (25694) esp-modem: Sending command: AT+CPIN?
I (25744) esp-modem: Line received:
 (d a)
I (25794) esp-modem: Line received: +CPIN: READY
 (2b 43)
I (25844) esp-modem: Line received:
 (d a)
I (25894) esp-modem: Line received: OK
 (4f 4b)
I (25894) esp-modem: Sending command: AT+CREG?
I (25944) esp-modem: Line received:
 (d a)
I (25994) esp-modem: Line received: +CREG: 0,3
 (2b 43)
I (26044) esp-modem: Line received:
 (d a)
I (26094) esp-modem: Line received: OK
 (4f 4b)
E (26094) sim800: sim800_wait_registration(524): waiting for network registration failed
E (26094) sim800: sim800_init(670): waiting for registration timed out
```

elktownlabs, 2022-11-13:
Das Modem antwortet.
Siehe [https://m2msupport.net/m2msupport/atcreg-network-registration/](https://m2msupport.net/m2msupport/atcreg-network-registration/)

`I (25994) esp-modem: Line received: +CREG: 0,3`
Er sucht hier nach einem GSM Netz und findet noch keines. Evtl. ne Weile laufen lassen. Das erste mal dauert es immer relativ lange. Irgendwann bricht er ab falls es garnicht geht. Und auch unbedingt eine Antenne anschließen. Offener SMA-Anschluss ist nicht unbedingt so Ideal wegen Reflektionen, Störungen der restlichen Elektronik usw.
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
elktownlabs, 2022-11-27:
Versuche mal folgende Änderung. Damit sollte die Kamera auch ein Roaming-Netz verwenden:

```
--- a/firmware/elkcam_firmware/components/modem/src/sim800.c
+++ b/firmware/elkcam_firmware/components/modem/src/sim800.c
@@ -211,7 +211,7 @@ static esp_err_t sim800_handle_waitregistration(modem_dce_t *dce, const char *li
         err = esp_modem_process_command_done(dce, MODEM_STATE_FAIL);
     } else if (!strncmp(line, "+CREG: ", strlen("+CREG: "))) {
         int value = line[9] - '0';
-        if (value ==1) {
+        if ((value ==1) || (value == 5)) {
             dce->registered = 1;
         }
         err = ESP_OK;
@@ -693,4 +693,4 @@ esp_err_t sim800_get_engineering_data(sim800_engineering_data_t* data)
         }
     }
     return res;
-}
\ No newline at end of file
+}
```

sirtet, 2022-11-27:
Stimmt genau... wenn du das schon als diff hast, kannst du das committen?

Was ist mit der EOF Änderung?

elktownlabs, 2022-12-01:
EOF-Newline hat wahrscheinlich mein Editor automatisch weggemacht. Ist irrelevant.
Ich mache einen Commit aber als bedingt reinkompiliert. Dann kann man es bei Bedarf noch rausnehmen.

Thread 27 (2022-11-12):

Kamera Probleme

sirtet, 2022-11-12:
Kamera hat Per Wifi Config UI 3-4 (schlechte) Bilder aufgenommen, jetzt keine mehr...
Erste 2 Bilder waren grünstichig und "verschoben"...
Hmm, ist das Linsen Cover grün? Wegnehmen...
Nächste Bilder sind nur grosse Farb-Pixel, Bunt wie von TV Testbild...
Dann plötzlich keine Bilder mehr, aber Fehler in der Konsole:

```
I (25824) OV2640: Set 146 to 1
I (25824) OV2640: Set 147 to 228
I (25824) camhandler: Setting sharpness to 0
I (25834) camhandler: Setting flip/mirror to 0
I (25834) camhandler: Waiting for camera to settle
I (29994) httpserver: Picture taken. Size = 45056
W (30024) httpd_txrx: httpd_sock_err: error in send : 104
I (30024) httpserver: Request headers lost
W (30024) httpd_txrx: httpd_sock_err: error in recv : 104
```

elktownlabs, 2022-11-13:
Da ist irgendetwas mit dem Datenstrom von dem Kameramodul nicht ok. Normalerweise müsste noch eine Meldung `Shortened data from ... to ...` nach dem `Picture taken. Size=...` kommen.

Das könnte bedeuten es kommt kein gültiges JPEG Bild an. Ich habe heute meine Murg-Cam zur Wartung heimgeholt und poste mal die Bild-Einstellungen sobald ich sie am Strom habe.

Das Kameramodul reagiert teilweise sehr energisch auf manche nicht vorgesehenen Konfigurationseinstellungen

sirtet, 2022-11-13:
Ja, erfolgreiche Bilder waren vor ich Parameter geändert habe...
Habe jetzt Defaults aus Code übernommen, hat nicht geholfen.
https://github.com/elktownlabs/murgcam/blob/98d05d2cdfb141ffb79fd98262dab560fdc96833/firmware/elkcam_firmware/main/config.h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

sirtet, 2022-11-17:
Weitere Beobachtungen:

Typische Meldungen:
```
I (440814) httpserver: Host 192.168.4.1 requested a picture.
I (440814) httpserver: Taking picture
I (440814) camhandler: Reinitializing cam
I (441114) OV2640: HID:9794
I (441154) camhandler: Configuring camera to global config settings
I (441154) camhandler: Setting pixel timing to 0
I (441154) camhandler: Setting picture quality to 63
I (441164) camhandler: Setting auto exposure to 2
I (441164) camhandler: Setting light mode to 0
I (441174) OV2640: Set 255 to 0
I (441174) OV2640: Set 124 to 0
I (441184) OV2640: Set 125 to 0
I (441184) camhandler: Setting color saturation to 0
I (441194) OV2640: Set 255 to 0
I (441194) OV2640: Set 124 to 0
I (441194) OV2640: Set 125 to 0
I (441204) camhandler: Setting brightness to 0
I (441204) OV2640: Set 255 to 0
I (441214) OV2640: Set 124 to 0
I (441214) OV2640: Set 125 to 0
I (441214) camhandler: Setting contrast to 0
I (441224) OV2640: Set 255 to 0
I (441224) OV2640: Set 124 to 0
I (441234) OV2640: Set 125 to 0
I (441234) camhandler: Setting hue to 0
I (441244) OV2640: Set 255 to 0
I (441244) OV2640: Set 146 to 1
I (441244) OV2640: Set 147 to 228
I (441254) camhandler: Setting sharpness to 0
I (441254) camhandler: Setting flip/mirror to 0
I (441264) camhandler: Waiting for camera to settle
I (445414) httpserver: Picture taken. Size = 40960
I (445514) httpserver: Request headers lost
```
- Quality scheint rückwärz zu funktionieren, Q=63 gibt kleinste Grösse, um 40k (`Picture taken. Size = 40960`). Q=10 ergibt um 80k.

- Ein Bild wird scheinbar schon aufgenommen, Linse abdecken gibt kleinere Grösse als gut beleuchtet in die Kamera schauen, allerdings nur um 10%

- Schaut die Antwort vom Sensor `OV2640: Set 255 to 0` etc.  gesund aus? Oder kann man daraus etwas ablesen?
Ist immer gleich, ausser bei Hue...
- ` httpserver: Request headers lost` ist normal?
- `httpd_sock_err: error in send : 104` scheint mit dem Client zu tun zu haben, sehe ich nur in Chrome, nicht in Firefox.
- Einmaliges Vorkommnis: Nach dem Ändern von Cell Pin von NULL-String auf 6400 stürzte die Kamera/(das System?) bis zum nächsten Reset ab, jede Bildanforderung sah so aus:
```
I (2297984) httpserver: Host 192.168.4.1 requested a picture.
I (2297984) httpserver: Taking picture
I (2297984) camhandler: Reinitializing cam
E (2298194) i2c: i2c command link malloc error
E (2298194) i2c: i2c command link malloc error
E (2298204) i2c: i2c command link malloc error
E (2298204) i2c: i2c command link malloc error
E (2298314) i2c: i2c command link malloc error
E (2298324) i2c: i2c command link malloc error
E (2298334) i2c: i2c command link malloc error
E (2298344) i2c: i2c command link malloc error
E (2298354) i2c: i2c command link malloc error
E (2298364) i2c: i2c command link malloc error
E (2298374) i2c: i2c command link malloc error
E (2298374) i2c: i2c command link malloc error
I (2298374) OV2640: HID:9794
E (2298374) i2c: i2c command link malloc error
E (2298374) i2c: i2c command link malloc error
E (2298394) i2c: i2c command link malloc error
E (2298394) i2c: i2c command link malloc error
E (2298394) i2c: i2c command link malloc error
E (2298394) i2c: i2c command link malloc error
E (2298414) i2c: i2c command link malloc error
E (2298414) i2c: i2c command link malloc error
E (2298424) i2c: i2c command link malloc error
E (2298424) i2c: i2c command link malloc error
E (2298434) i2c: i2c command link malloc error
E (2298434) i2c: i2c command link malloc error
E (2298444) i2c: i2c command link malloc error
E (2298444) i2c: i2c command link malloc error
E (2298454) i2c: i2c command link malloc error
E (2298454) i2c: i2c command link malloc error
E (2298464) i2c: i2c command link malloc error
E (2298464) i2c: i2c command link malloc error
E (2298474) i2c: i2c command link malloc error
E (2298474) i2c: i2c command link malloc error
E (2298484) i2c: i2c command link malloc error
E (2298484) i2c: i2c command link malloc error
E (2298494) i2c: i2c command link malloc error
E (2298494) i2c: i2c command link malloc error
E (2298504) i2c: i2c command link malloc error
E (2298504) i2c: i2c command link malloc error
E (2298514) i2c: i2c command link malloc error
E (2298514) i2c: i2c command link malloc error
E (2298524) i2c: i2c command link malloc error
E (2298524) i2c: i2c command link malloc error
E (2298534) i2c: i2c command link malloc error
E (2298534) i2c: i2c command link malloc error
E (2298544) i2c: i2c command link malloc error
E (2298544) i2c: i2c command link malloc error
E (2298554) i2c: i2c command link malloc error
E (2298554) i2c: i2c command link malloc error
E (2298564) i2c: i2c command link malloc error
E (2298564) i2c: i2c command link malloc error
E (2298574) i2c: i2c command link malloc error
E (2298574) i2c: i2c command link malloc error
E (2298584) i2c: i2c command link malloc error
E (2298584) i2c: i2c command link malloc error
E (2298594) i2c: i2c command link malloc error
E (2298594) i2c: i2c command link malloc error
E (2298604) i2c: i2c command link malloc error
E (2298604) i2c: i2c command link malloc error
E (2298614) i2c: i2c command link malloc error
E (2298614) i2c: i2c command link malloc error
E (2298624) i2c: i2c command link malloc error
E (2298624) i2c: i2c command link malloc error
E (2298634) i2c: i2c command link malloc error
E (2298634) i2c: i2c command link malloc error
E (2298644) i2c: i2c command link malloc error
E (2298644) i2c: i2c command link malloc error
E (2298654) i2c: i2c command link malloc error
E (2298654) i2c: i2c command link malloc error
E (2298664) i2c: i2c command link malloc error
E (2298664) i2c: i2c command link malloc error
E (2298674) i2c: i2c command link malloc error
E (2298674) i2c: i2c command link malloc error
E (2298694) i2c: i2c command link malloc error
E (2298694) i2c: i2c command link malloc error
E (2298704) i2c: i2c command link malloc error
E (2298704) i2c: i2c command link malloc error
E (2298714) i2c: i2c command link malloc error
E (2298714) i2c: i2c command link malloc error
E (2298724) i2c: i2c command link malloc error
E (2298724) i2c: i2c command link malloc error
E (2298734) i2c: i2c command link malloc error
E (2298734) i2c: i2c command link malloc error
E (2298744) i2c: i2c command link malloc error
E (2298744) i2c: i2c command link malloc error
E (2298754) i2c: i2c command link malloc error
E (2298754) i2c: i2c command link malloc error
E (2298764) i2c: i2c command link malloc error
E (2298764) i2c: i2c command link malloc error
E (2298774) i2c: i2c command link malloc error
E (2298774) i2c: i2c command link malloc error
E (2298784) i2c: i2c command link malloc error
E (2298784) i2c: i2c command link malloc error
E (2298794) i2c: i2c command link malloc error
E (2298794) i2c: i2c command link malloc error
E (2298804) i2c: i2c command link malloc error
E (2298804) i2c: i2c command link malloc error
E (2298814) i2c: i2c command link malloc error
E (2298814) i2c: i2c command link malloc error
E (2298824) i2c: i2c command link malloc error
E (2298824) i2c: i2c command link malloc error
E (2298834) i2c: i2c command link malloc error
E (2298834) i2c: i2c command link malloc error
E (2298844) i2c: i2c command link malloc error
E (2298844) i2c: i2c command link malloc error
E (2298854) i2c: i2c command link malloc error
E (2298854) i2c: i2c command link malloc error
E (2298864) i2c: i2c command link malloc error
E (2298864) i2c: i2c command link malloc error
E (2298874) i2c: i2c command link malloc error
E (2298874) i2c: i2c command link malloc error
E (2298884) i2c: i2c command link malloc error
E (2298884) i2c: i2c command link malloc error
E (2298894) i2c: i2c command link malloc error
E (2298894) i2c: i2c command link malloc error
E (2298904) i2c: i2c command link malloc error
E (2298904) i2c: i2c command link malloc error
E (2298914) i2c: i2c command link malloc error
E (2298914) i2c: i2c command link malloc error
E (2298924) i2c: i2c command link malloc error
E (2298924) i2c: i2c command link malloc error
E (2298934) i2c: i2c command link malloc error
E (2298934) i2c: i2c command link malloc error
E (2298944) i2c: i2c command link malloc error
E (2298944) i2c: i2c command link malloc error
E (2298954) i2c: i2c command link malloc error
E (2298954) i2c: i2c command link malloc error
E (2298964) i2c: i2c command link malloc error
E (2298964) i2c: i2c command link malloc error
E (2298974) i2c: i2c command link malloc error
E (2298974) i2c: i2c command link malloc error
E (2298984) i2c: i2c command link malloc error
E (2298984) i2c: i2c command link malloc error
E (2298994) i2c: i2c command link malloc error
E (2298994) i2c: i2c command link malloc error
E (2299004) i2c: i2c command link malloc error
E (2299004) i2c: i2c command link malloc error
E (2299014) i2c: i2c command link malloc error
E (2299014) i2c: i2c command link malloc error
E (2299024) i2c: i2c command link malloc error
E (2299024) i2c: i2c command link malloc error
E (2299034) i2c: i2c command link malloc error
E (2299034) i2c: i2c command link malloc error
E (2299044) i2c: i2c command link malloc error
E (2299044) i2c: i2c command link malloc error
E (2299054) i2c: i2c command link malloc error
E (2299054) i2c: i2c command link malloc error
E (2299064) i2c: i2c command link malloc error
E (2299064) i2c: i2c command link malloc error
E (2299074) i2c: i2c command link malloc error
E (2299074) i2c: i2c command link malloc error
E (2299084) i2c: i2c command link malloc error
E (2299084) i2c: i2c command link malloc error
E (2299104) i2c: i2c command link malloc error
E (2299104) i2c: i2c command link malloc error
E (2299114) i2c: i2c command link malloc error
E (2299114) i2c: i2c command link malloc error
E (2299124) i2c: i2c command link malloc error
E (2299124) i2c: i2c command link malloc error
E (2299134) i2c: i2c command link malloc error
E (2299134) i2c: i2c command link malloc error
E (2299144) i2c: i2c command link malloc error
E (2299144) i2c: i2c command link malloc error
E (2299154) i2c: i2c command link malloc error
E (2299154) i2c: i2c command link malloc error
E (2299164) i2c: i2c command link malloc error
E (2299164) i2c: i2c command link malloc error
E (2299164) i2c: i2c command link malloc error
E (2299164) i2c: i2c command link malloc error
E (2299184) i2c: i2c command link malloc error
E (2299184) i2c: i2c command link malloc error
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
sirtet, 2022-11-18:
Ach, schlechte Lötstelle...
An
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

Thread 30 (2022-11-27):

Video statt Photo im Wifi UI, für leichteres Setup?

sirtet, 2022-11-27:
Ist es möglich statt einem Vorschau- Bild ein Video zu haben?

Ein Video würde das Ausrichten erleichtern.
Und auch das Setzen der Bildeinstellungen, falls die Einstellungen auf das Live Video anwendbar wären, resp. bei Slider-loslassen die Einstellungen gespeichert und der Stream neu gestartet würde.

elktownlabs, 2022-12-01:
Leider mit dem ESP32-S2 nicht möglich da nicht genug Rechenleistung mit nur einem Core. Evtl. Wechsel auf den ESP32-S3 mit zwei Cores. Dann sollte es gehen.

Closed 2022-12-01.

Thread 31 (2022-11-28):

Server Admin-UI sollte keine Vorgaben machen von sich aus, nur zeigen was in der cam steht

sirtet, 2022-11-28:
Damit nicht versehentlich neue Werte gesetzt werden, sollte das UI nur den Momentan-Zustand der Kamera zeigen,
und Daten zum Upload vorsehen nur dann wenn aktiv etwas geändert wurde.
also die upload-felder leer lassen, bis jemand einen EDIT macht, bei SAVE werden die Werte dann in den zu uploadenden Datensatz eingefügt.

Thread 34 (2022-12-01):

Wechsel auf ESP32-S3 prüfen

elktownlabs, 2022-12-01:
Evtl. auf den neuen ESP32-S3 wechseln. Dieser hat wie der frühere ESP32 wieder zwei Cores. Damit sollten Features wie Live-Video zur Ausrichtung der Kamera wieder möglich sein.

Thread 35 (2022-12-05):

Link first and last photo of the day with sunset/sunrise

elktownlabs, 2022-12-05:
Add an option to use sunset / sunrise times (PHP date_sunset(), date_sunrise()) instead of fixed times for the first and last photo of the day. This would avoid taking too many dark pictures and wasting battery capacity.

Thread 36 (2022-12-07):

Wifi admin: Transparentes Referenzbild einblenden für leichtes neu-Ausrichten

sirtet, 2022-12-07:
Wenn die Kamera für Service demontiert wird und wieder montiert, kann es schwierig werden den gleichen Bildausschnitt zu finden.
Da würde es helfen, insbesondere falls mal im WIFI Admin die Video-Vorschau kommt,
man könnte dem live Bild ein halbtransparentes Referenzbild überlagern.
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

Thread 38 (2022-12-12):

Server Pfad sollte nicht "hardcoded" sein.

sirtet, 2022-12-12:
für einen Production Build wird momentan fix von __webcam__ ausgegangen.
https://github.com/elktownlabs/murgcam/blob/98d05d2cdfb141ffb79fd98262dab560fdc96833/web-if/src/router/index.js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
Das sollte konfigurierbar sein in .env.* (falls es überhaupt nötig ist).
Kann das nicht fix auf einen relativen Pfad gesetzt werden, so dass man es wo auch immer deployen kann?

sirtet, 2022-12-12:
PS:
Wenn der Pfad in __base__ falsch ist, erzeugt das keine Fehlermeldung im Browser resp. Browser Dev. Console, sondern es wird einfach kein Content gerendert. Gibt nur eine weisse leere Seite. Fies...

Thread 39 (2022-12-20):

3D Druck: CCD-Halter steifer machen

sirtet, 2022-12-20:
Der Bogen der die Optik aufnimmt, sollte ev. breiter gemacht werden, damit er steifer wird, die relativ schwere Optik besser trägt ( die könnte sich vielleicht bei heissen Temperaturen langsam zu neigen beginnen).

elktownlabs, 2022-12-21:
Bisher keine Probleme bei der Murg-Cam damit. Die Bögen sind mit 100% Füllung in ABS gedruckt.

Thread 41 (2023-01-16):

Falsche APN Einstellung erkennen

sirtet, 2023-01-16:
Zur Referenz: So sieht das Ende vom Boot-Log aus bei falschem APN:

````
I (27725) cellmodem: APN: internet
I (27725) cellmodem: PIN: 7190
I (27725) cellmodem: Using no APN authentication
I (27735) esp-modem: Sending command: AT+CGDCONT=1,"IP","internet"
I (27775) esp-modem: Line received:
 (d a)
I (27825) esp-modem: Line received: OK
 (4f 4b)
I (27825) esp-modem: Sending command: ATD*99#
I (27875) esp-modem: Line received:
 (d a)
I (27925) esp-modem: Line received: CONNECT
 (43 4f)
I (27925) cellmodem: Modem PPP Started
I (27925) ina226: Starting voltage / current sampling
I (27925) ina226: Received notification value 1
I (27935) cellmodem: Waiting for IP address
I (27935) ina226: Starting sampling loop. Configuring INA226 for continuous averaging
I (34435) esp-netif_lwip-ppp: Connection lost
I (34435) ina226: Stopping voltage / current sampling
I (34435) cellmodem: Modem Disconnect from PPP Server
I (35145) ina226: Sampling results: Min voltage: 12.221623; Avg. current: 0.030283
E (57935) cellmodem: PPP not conneced. Timeout.
I (57935) main: Closing modem connection
I (57935) main: Modem power key on for 1.2s
I (59135) main: Modem power key off and wait 1s
W (59965) esp-modem: Rx Break
I (60135) main: Power down modem now
I (60135) main: Using sleep time from config: 600 secs
I (60135) main: Up for 58810 ms. Going to sleep for 541190 ms
````

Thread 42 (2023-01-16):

APN Einstellung via WEB-UI entfernen oder sicherer machen

sirtet, 2023-01-16:
Die Einstellungen zur SIM Karte werden wohl nie ändern ohne dass die SIM gewechselt wird. (Oder doch?)
Es besteht momentan die Gefahr, dass etwas versehentlich verstellt wird und die Einstellung dann vor Ort korrigiert werden muss.
Etwa wenn ein ungültiger APN oder PIN Hochgeladen wird.
Sollten diese Daten nicht read-only sein im WebUI?
Einstellbar nur am WIFI-UI, dann wenn man auch vor Ort ist zum SIM wechseln?

Falls das remote änderbar bleiben soll, sollte man vielleicht eine Sicherheitsabfrage einbauen, dass das nur super bewusst gemacht werden kann?

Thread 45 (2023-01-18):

SOFTWARE Sollte ein String sein, kein Datum, oder?

sirtet, 2023-01-18:
Etwas wie `Murgcam`...
https://github.com/elktownlabs/murgcam/blob/23df4dbb274391b16a67ac1fe7236453216c96b4/web-backend/api/upload.php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

sirtet, 2023-01-18:
Laut [Exif 2.3 standard](http://www.cipa.jp/std/documents/e/DC-008-2012_E.pdf) etwas wie `Murgcam 1.02`
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

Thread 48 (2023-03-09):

Finish refphoto function

sirtet, 2023-03-09:
The current implementation only returns the same sample jpg for all calibration points:

https://github.com/elktownlabs/murgcam/blob/23df4dbb274391b16a67ac1fe7236453216c96b4/web-backend/api/rivermap.php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

i added a Folder `ref` in `admin/photos` and deliver photos from there:

```
208 ////////////////////////////////////
209 // -- API subfunction refphoto -- //
210 ////////////////////////////////////
211 // Returns a list of all files matching the provided search criteria
212
213 if(isset($_GET['refphoto'])) {
214     $reflabel = $_GET['refphoto'];
215     header('Content-Type: image/jpeg');
216     header('Content-Disposition: inline');
217     switch ($reflabel) {
218         case 'min':
219             print(file_get_contents("../photos/ref/min.jpg"));
220             break;
221         case 'med':
222             print(file_get_contents("../photos/ref/med.jpg"));
223             break;
224         case 'max':
225             print(file_get_contents("../photos/ref/max.jpg"));
226     }
227     exit(0);
228   }
```

This works.
Was/is there a plan for how the final implementation should look like?
I think it's a good idea to have the ref-images close to the cam_ photos, they are both "user"-Data, and it gets a bit easyer to copy/move files around.

How i work with this Setup is:
1. browse for a good ref. image in the UI,
2. then copy that to eg. `ref/min-cam_6409f5d877458.jpg`
  possibly also `peter-p-min-cam_6409f5d877458.jpg` for someone else's recommendation.
3. Then, whichever i decide to currently use, i copy to `min.jpg`
4. When i don't have a proper ref.Image yet, i add some text to the image. Commandline example:
 `convert -pointsize 60 -fill white -annotate +100+150 'Reference Image missing.\nThe red Mark should roughly be High flow.' min-cam_6409f5d877458.jpg max.jpg`

elktownlabs, 2023-03-14:
The reference images are now on the MurgCam server and the refphoto function implemented as suggested above.

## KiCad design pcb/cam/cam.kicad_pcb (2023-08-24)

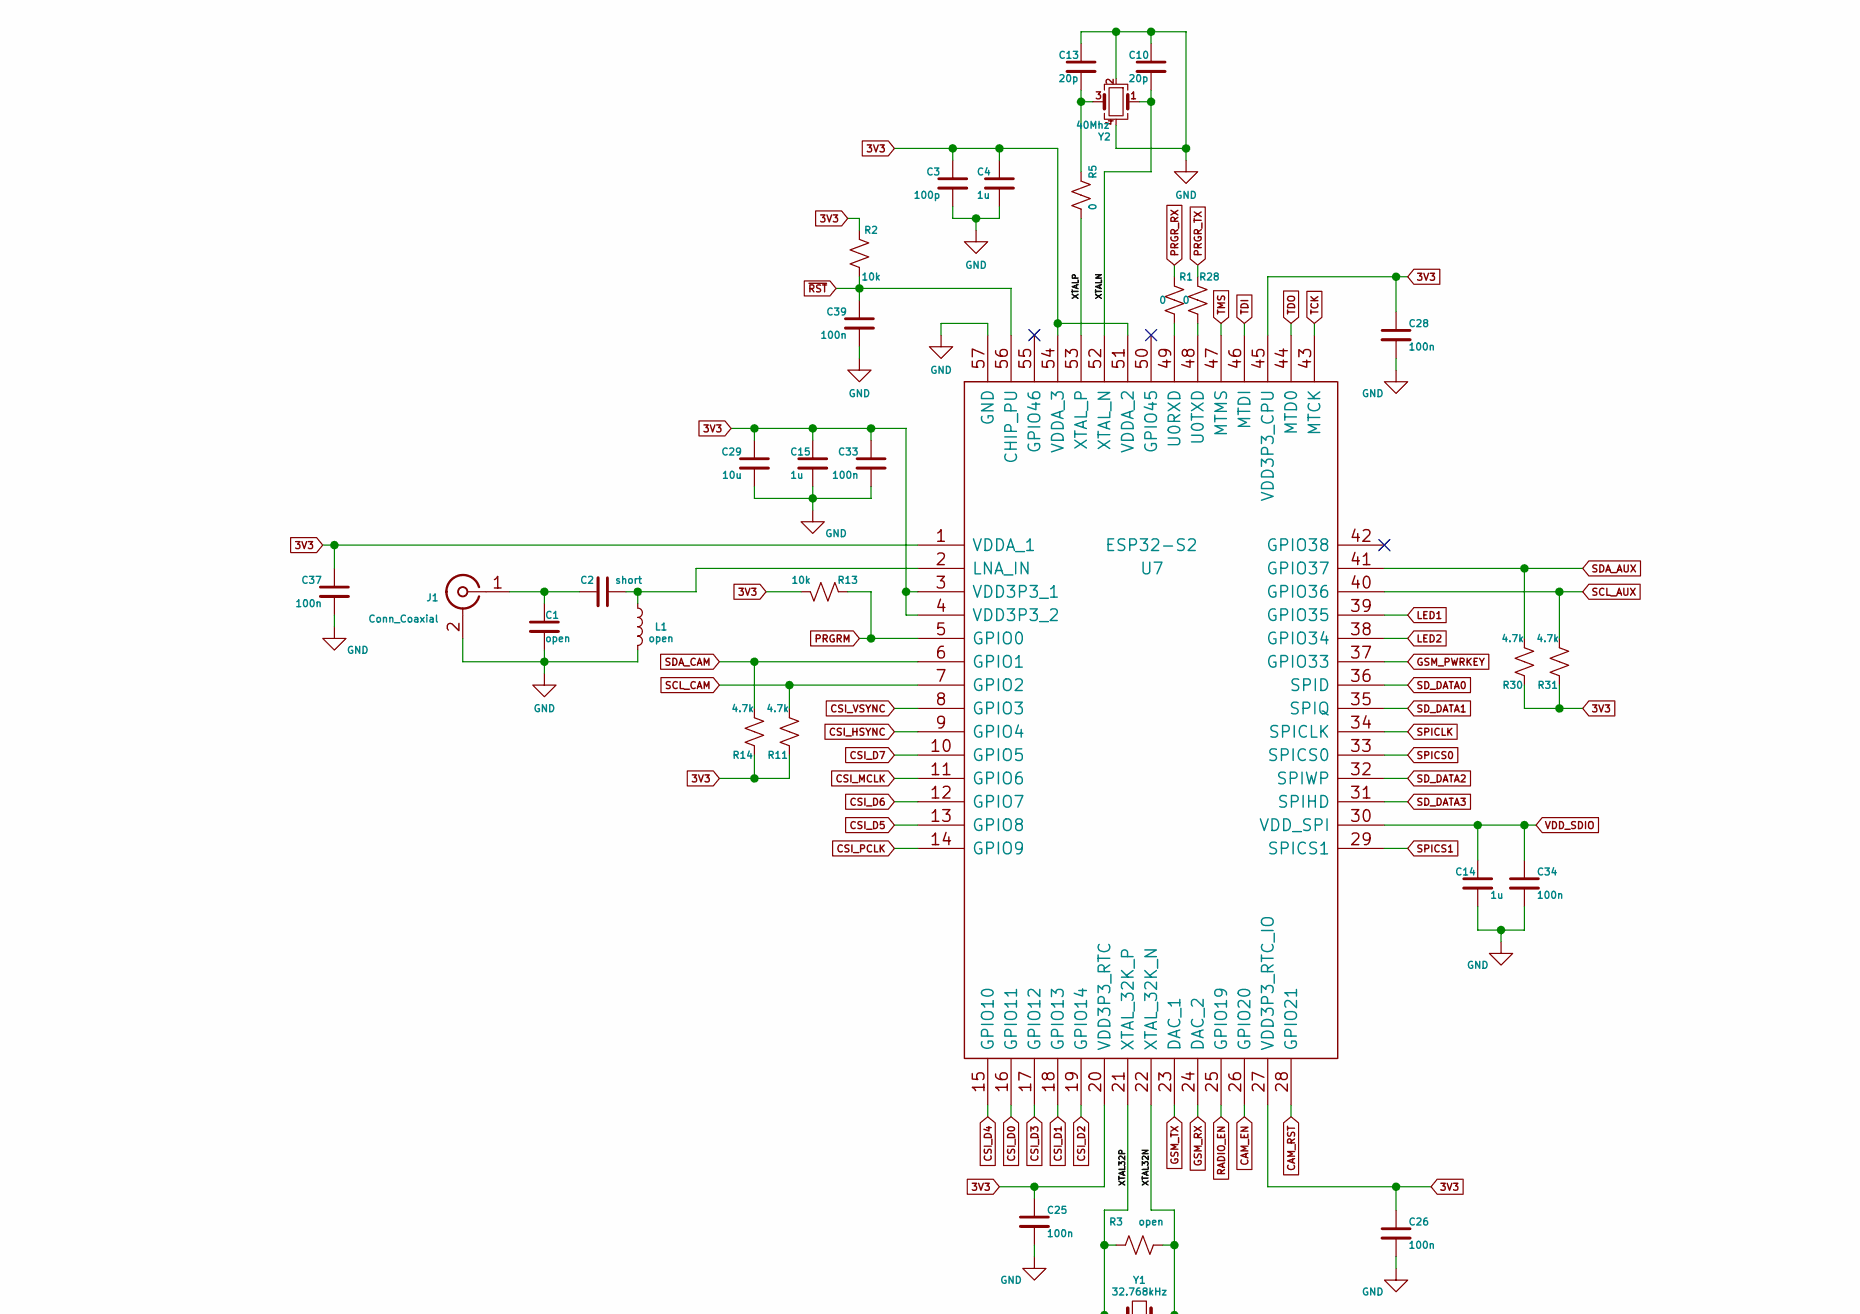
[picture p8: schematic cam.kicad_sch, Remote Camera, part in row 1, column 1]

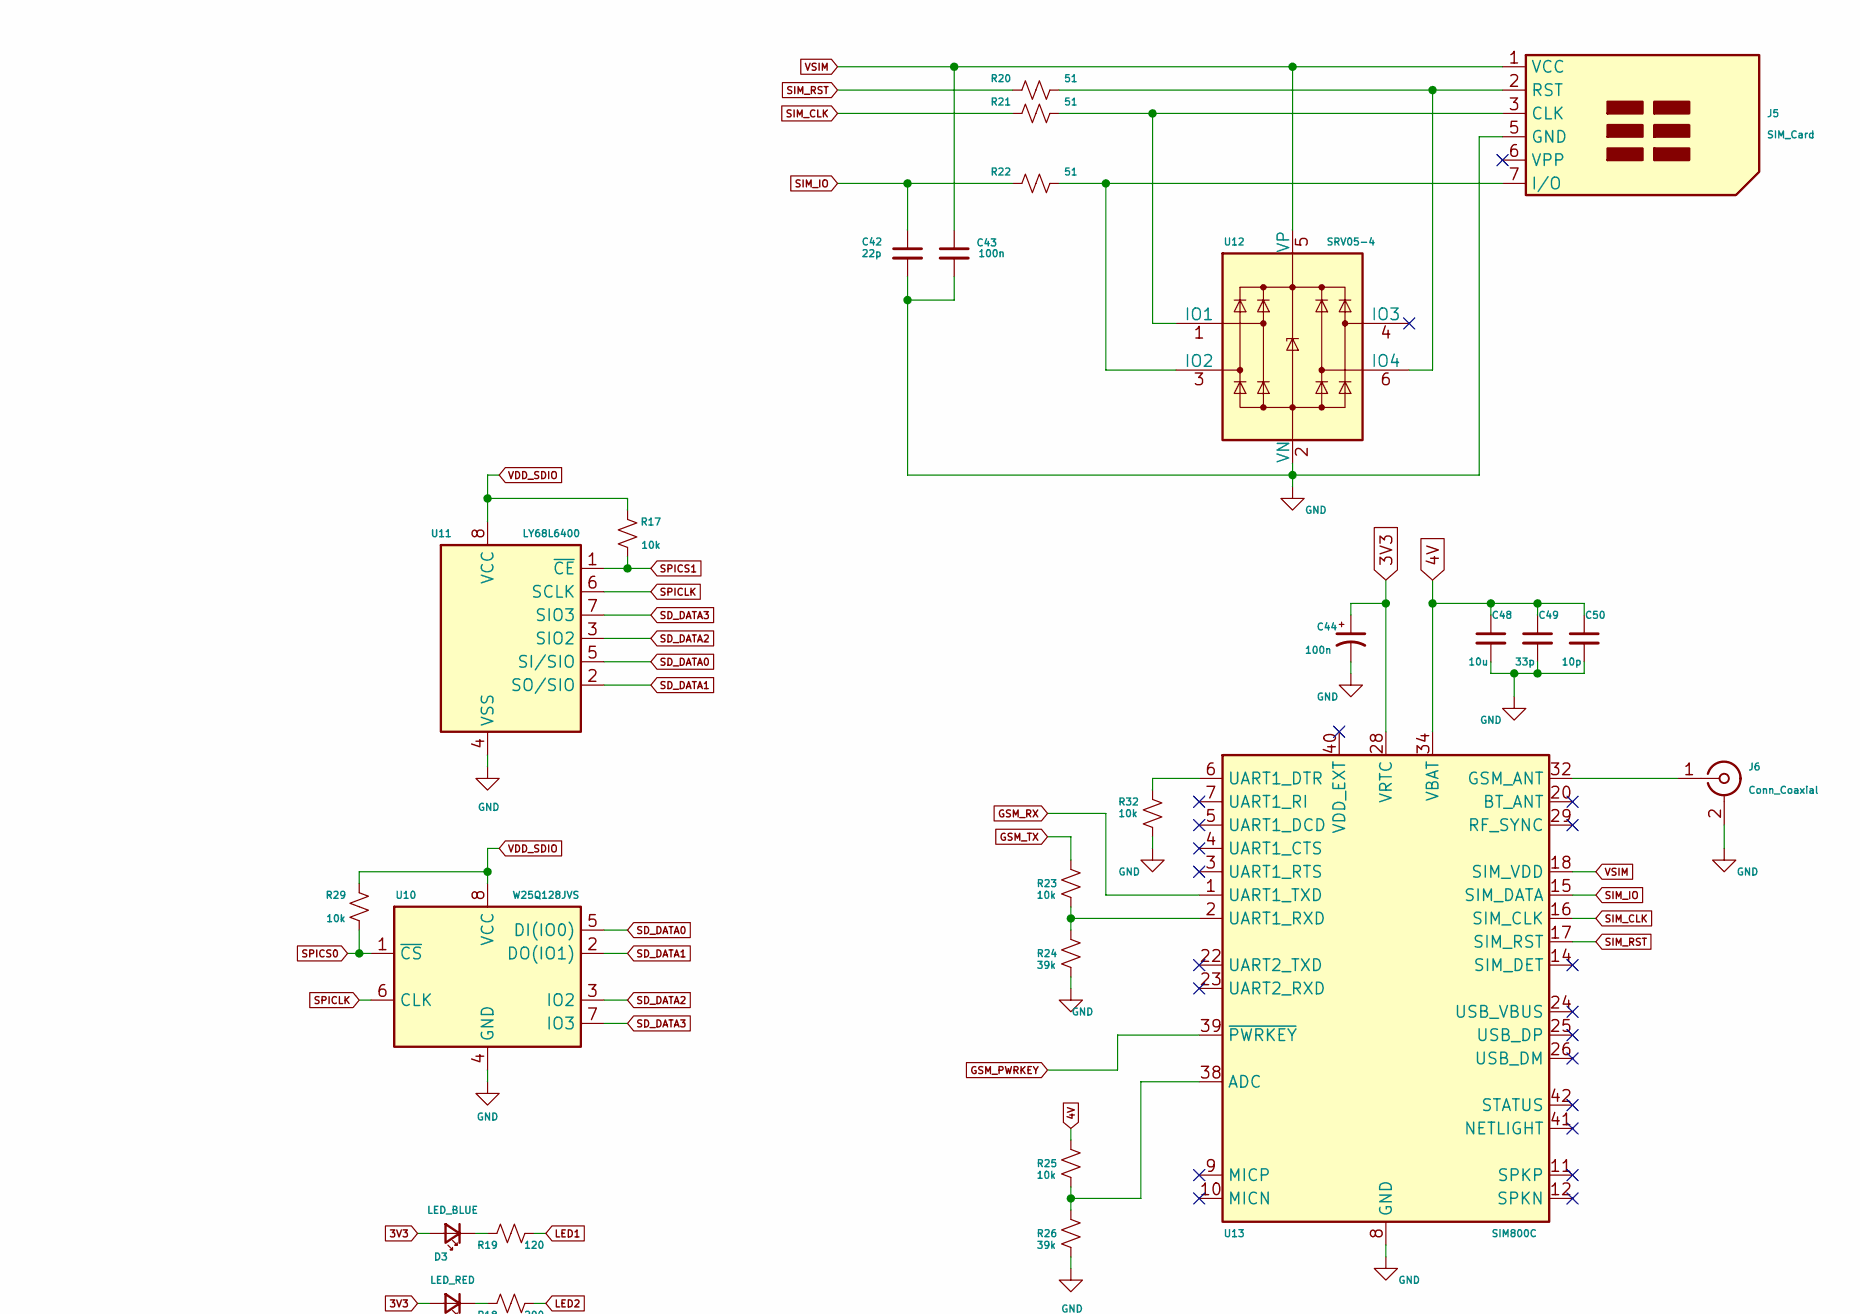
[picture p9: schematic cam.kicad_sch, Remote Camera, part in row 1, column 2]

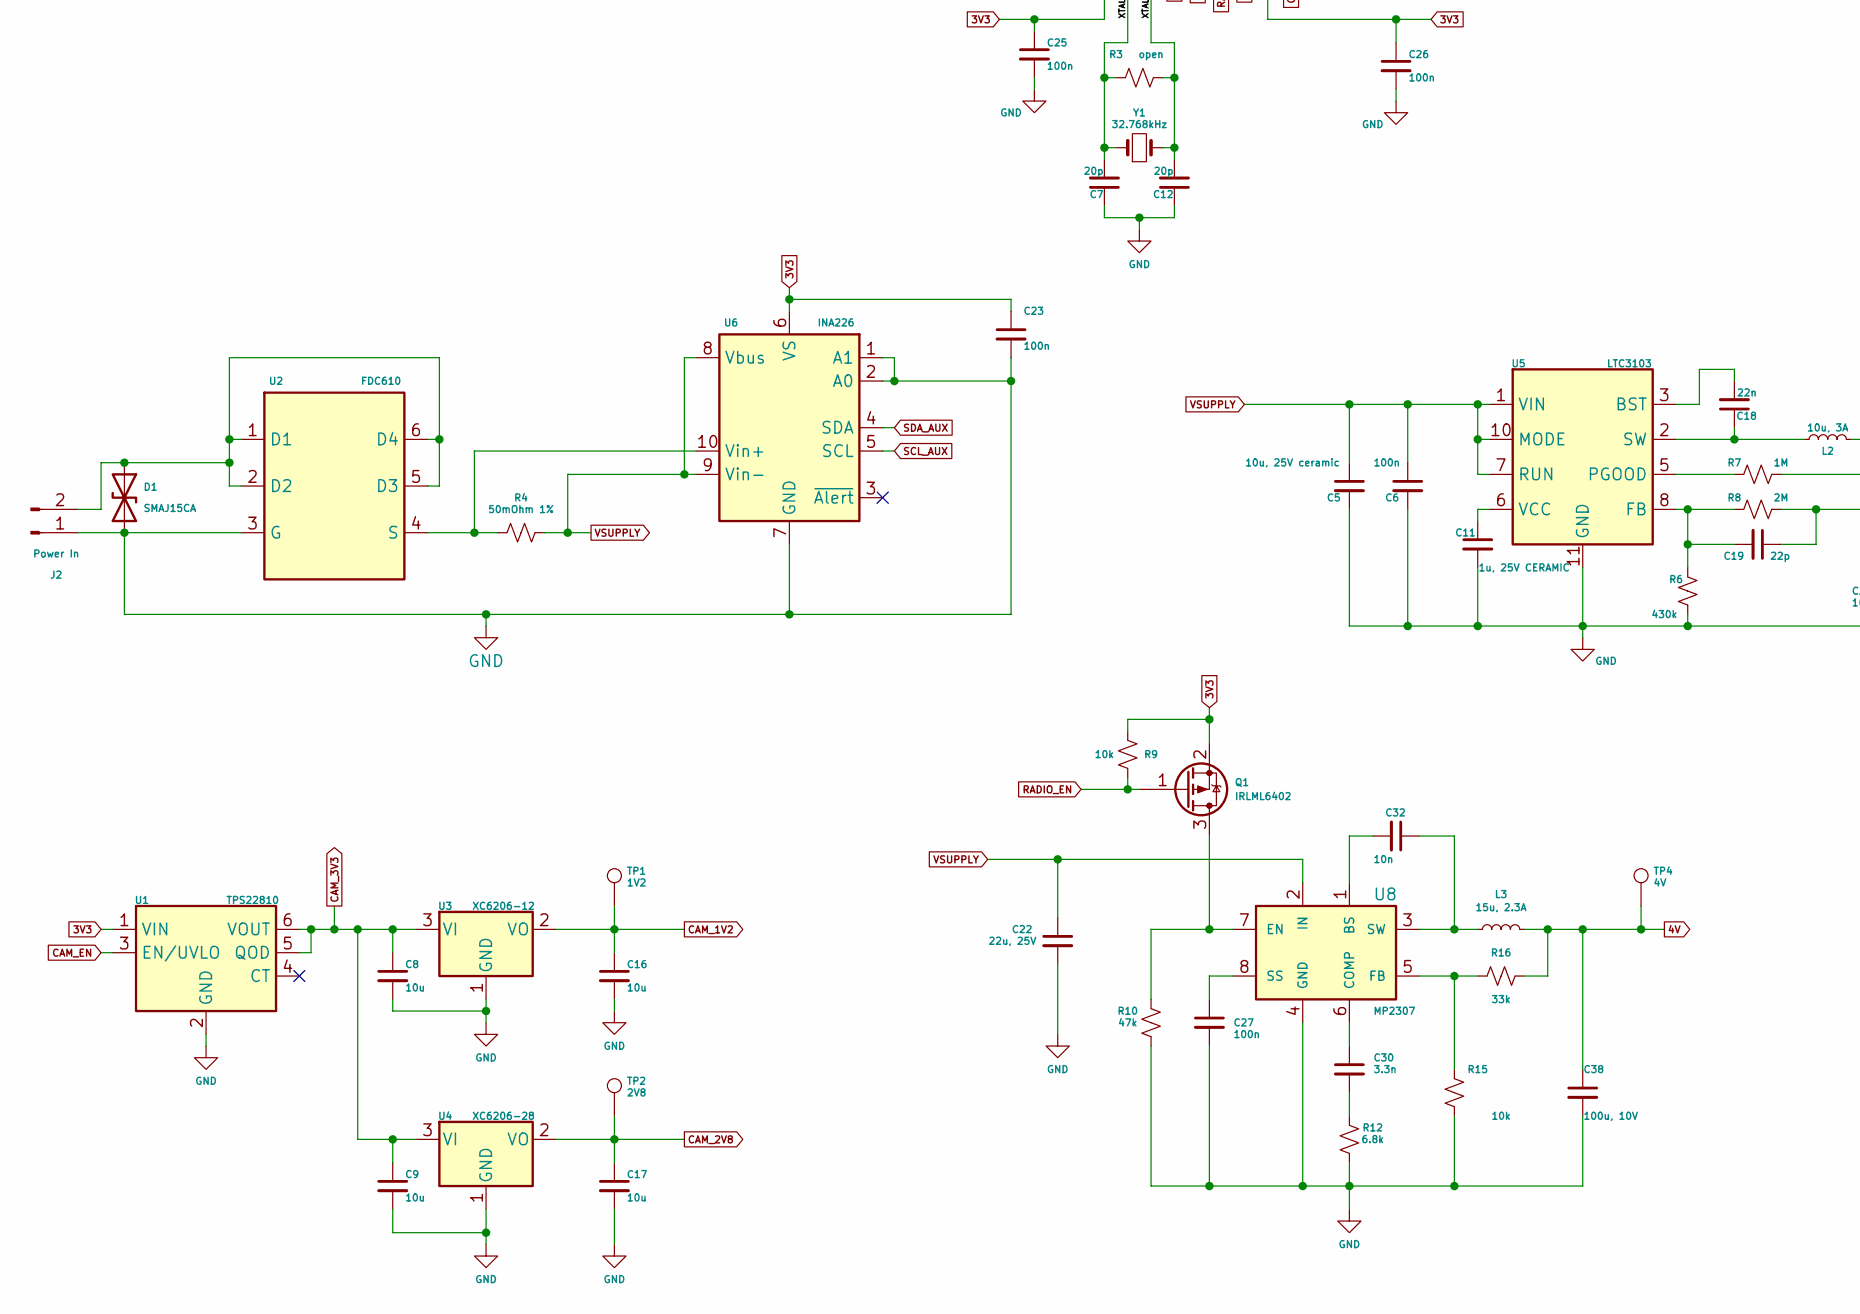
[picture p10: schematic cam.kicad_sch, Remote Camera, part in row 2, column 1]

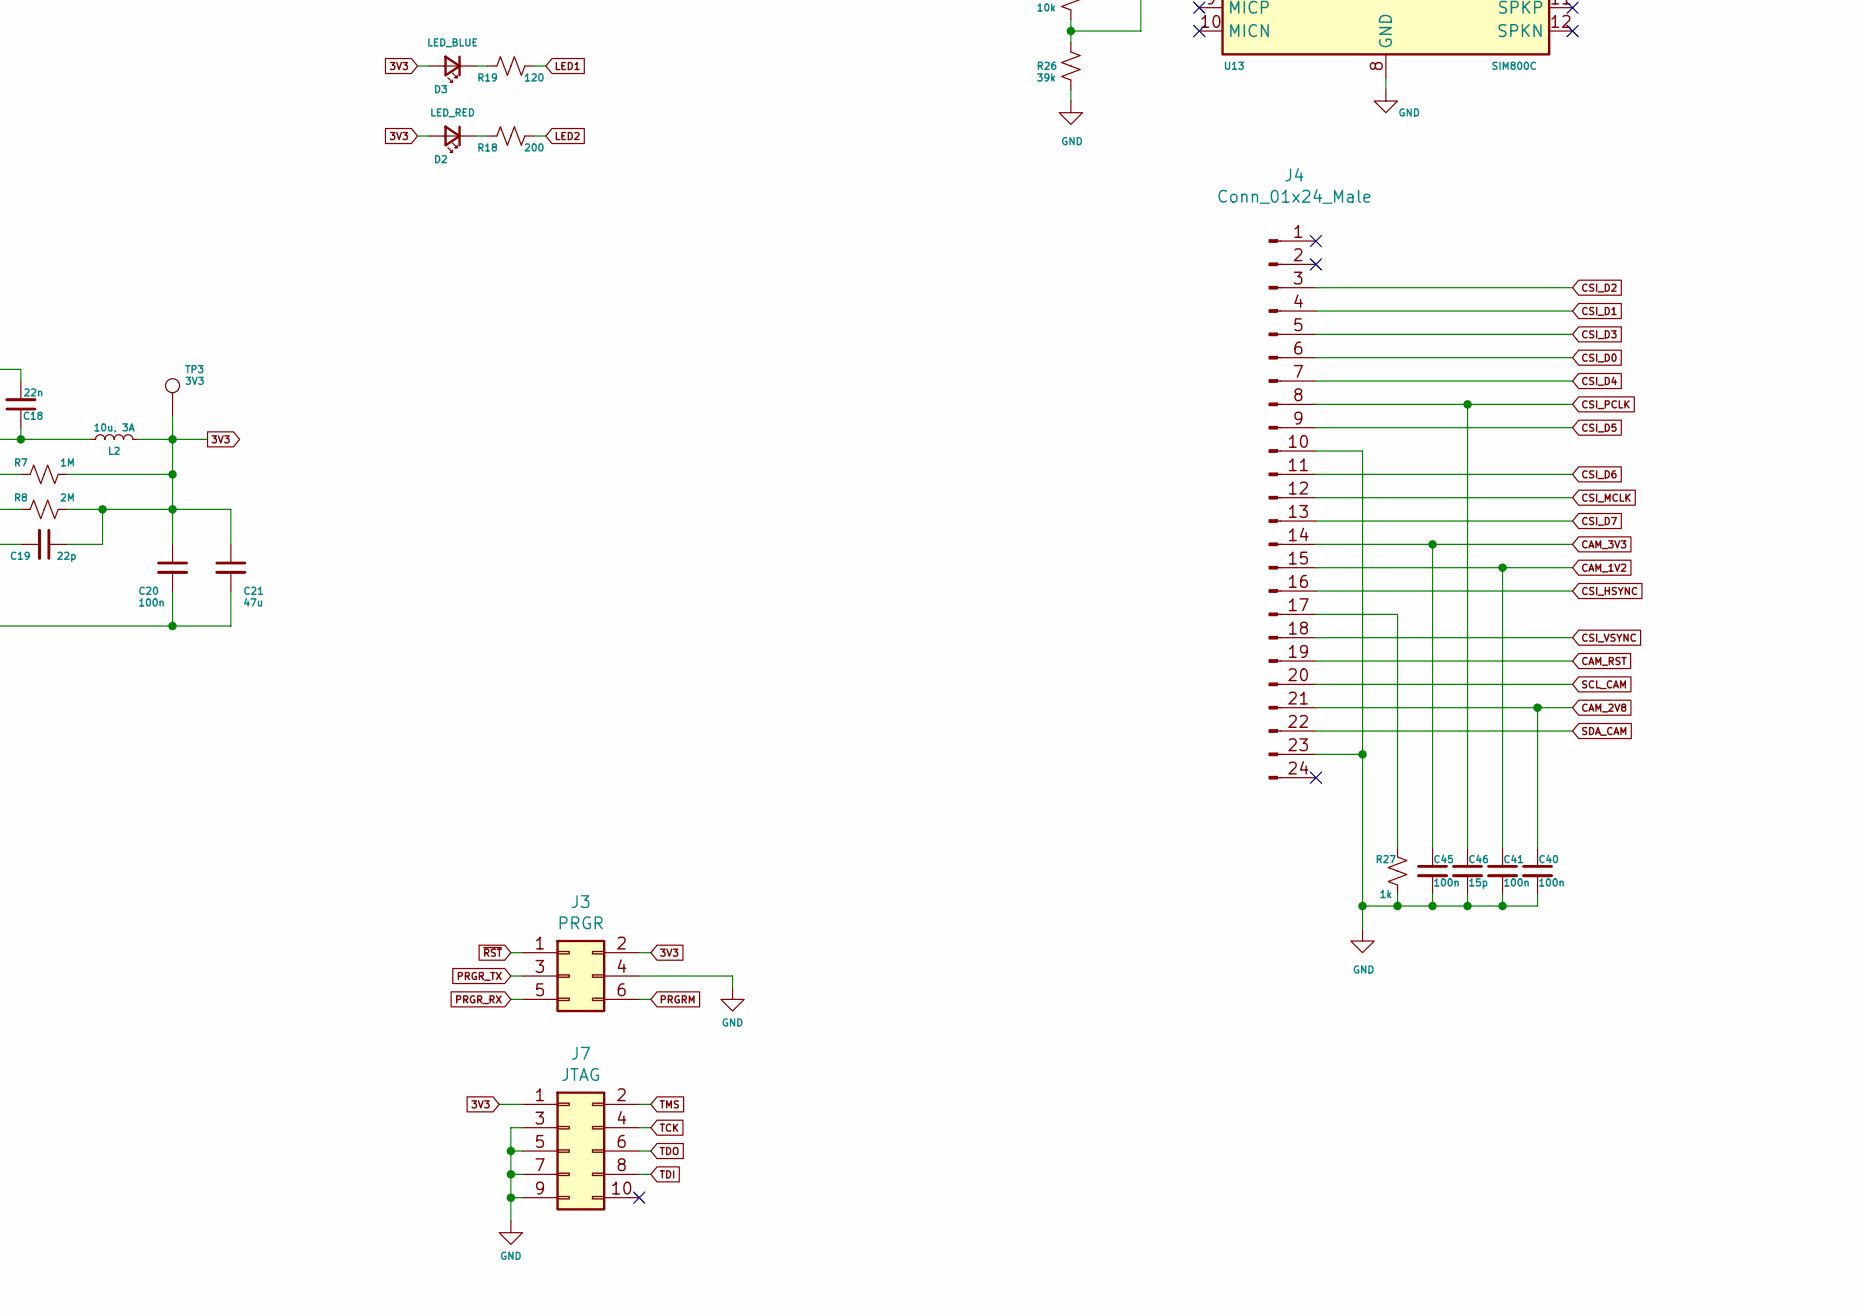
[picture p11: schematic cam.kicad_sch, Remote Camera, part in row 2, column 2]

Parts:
C1: open; C_0603_1608Metric
C2: short; C_0603_1608Metric
C3: 100p; C_0603_1608Metric
C4, C14, C15: 1u; C_0603_1608Metric
C5: 10u, 25V ceramic; C_1210_3225Metric
C6, C20, C23, C25, C26, C27, C28, C33, C34, C37, C39, C40, C41, C43, C44, C45: 100n; C_0603_1608Metric
C7, C10, C12, C13: 20p; C_0603_1608Metric
C8, C9, C16, C17, C29, C48: 10u; C_0805_2012Metric
C11: 1u, 25V CERAMIC; C_0805_2012Metric
C18: 22n; C_0603_1608Metric
C19, C42: 22p; C_0603_1608Metric
C21: 47u; C_1206_3216Metric
C22: 22u, 25V; C_1210_3225Metric
C30: 3.3n; C_0603_1608Metric
C32: 10n; C_0603_1608Metric
C38: 100u, 10V; C_1206_3216Metric
C46: 15p; C_0603_1608Metric
C49: 33p; C_0603_1608Metric
C50: 10p; C_0603_1608Metric
D1: SMAJ15CA; D_SMA
D2: LED_RED; LED_0603_1608Metric
D3: LED_BLUE; LED_0603_1608Metric
J1, J6: Conn_Coaxial; U.FL_Hirose_U.FL-R-SMT-1_Vertical
J2: Power In; JST_XH_B2B-XH-A_1x02_P2.50mm_Vertical
J3: PRGR; PinHeader_2x03_P1.27mm_Vertical
J4: Conn_01x24_Male; Hirose_FH12-24S-0.5SH_1x24-1MP_P0.50mm_Horizontal
J5: SIM_Card; MicroSim_6P
J7: JTAG; PinHeader_2x05_P1.27mm_Vertical
L1: open; L_0603_1608Metric
L2: 10u, 3A; IND_LPS3314-222MRC
L3: 15u, 2.3A; MSS7348-XXXMEC
Q1: IRLML6402; SOT-23
R1, R28: 0; R_0603_1608Metric
R2, R9, R13, R15, R17, R23, R25, R29, R32: 10k; R_0603_1608Metric
R3: open; R_0603_1608Metric
R4: 50mOhm 1%; L_1206_3216Metric
R5: 0; L_0603_1608Metric
R6: 430k; R_0603_1608Metric
R7: 1M; R_0603_1608Metric
R8: 2M; R_0603_1608Metric
R10: 47k; R_0603_1608Metric
R11, R14, R30, R31: 4.7k; R_0603_1608Metric
R12: 6.8k; R_0603_1608Metric
R16: 33k; R_0603_1608Metric
R18: 200; R_0603_1608Metric
R19: 120; R_0603_1608Metric
R20, R21, R22: 51; R_0603_1608Metric
R24, R26: 39k; R_0603_1608Metric
R27: 1k; R_0603_1608Metric
TP1: 1V2; TestPoint_Loop_D2.60mm_Drill0.9mm_Beaded
TP2: 2V8; TestPoint_Loop_D2.60mm_Drill0.9mm_Beaded
TP3: 3V3; TestPoint_Loop_D2.60mm_Drill0.9mm_Beaded
TP4: 4V; TestPoint_Loop_D2.60mm_Drill0.9mm_Beaded
U1: TPS22810; SOT-23-6
U2: FDC610; TSSOP-8_3x3mm_P0.65mm
U3: XC6206-12; SOT-23
U4: XC6206-28; SOT-23
U5: LTC3103; MSOP-10-1EP_3x3mm_P0.5mm_EP1.68x1.88mm
U6: INA226; VSSOP-10_3x3mm_P0.5mm
U7: ESP32-S2; QFN40P700X700X90-57N-D; Manufacturer_Part_Number ESP32-S2; Mouser Part Number 356-ESP32-S2
U8: MP2307; SOIC-8-1EP_3.9x4.9mm_P1.27mm_EP2.514x3.2mm
U10: W25Q128JVS; SOIC-8_5.23x5.23mm_P1.27mm
U11: LY68L6400; SOIC-8_3.9x4.9mm_P1.27mm
U12: SRV05-4; SOT-23-6
U13: SIM800C; SIMCom_SIM800C
Y1: 32.768kHz; Crystal_SMD_SeikoEpson_MC306-4Pin_8.0x3.2mm
Y2: 40Mhz; Crystal_SMD_5032-4Pin_5.0x3.2mm

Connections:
3V3: C3.1, C4.1, C15.1, C19.1, C20.1, C21.1, C23.1, C25.1, C26.1, C28.1, C29.1, C33.1, C37.1, C44.1, D2.2 (A), D3.2 (A), J3.2, J7.1, L2.2, Q1.2 (S), R2.1, R7.2, R8.2, R9.1, R11.1, R13.2, R14.1, R30.1, R31.1, TP3.1, U1.1 (VIN), U6.6 (VS), U7.1 (VDDA_1), U7.3 (VDD3P3_1), U7.4 (VDD3P3_2), U7.20 (VDD3P3_RTC), U7.27 (VDD3P3_RTC_IO), U7.45 (VDD3P3_CPU), U7.51 (VDDA_2), U7.54 (VDDA_3), U13.28 (VRTC)
4V: C38.1, C48.1, C49.1, C50.1, L3.2, R16.2, R25.1, TP4.1, U13.34 (VBAT), U13.35 (VBAT)
/XTAL32N: C12.2, R3.2, U7.22 (XTAL_32K_N), Y1.2
/XTAL32P: C7.2, R3.1, U7.21 (XTAL_32K_P), Y1.1
/XTALN: C10.2, U7.52 (XTAL_N), Y2.1
/XTALP: R5.2, U7.53 (XTAL_P)
CAM_1V2: C16.1, C41.1, J4.15, TP1.1, U3.2 (VO)
CAM_2V8: C17.1, C40.1, J4.21, TP2.1, U4.2 (VO)
CAM_3V3: C8.1, C9.1, C45.1, J4.14, U1.5 (QOD), U1.6 (VOUT), U3.3 (VI), U4.3 (VI)
CAM_EN: U1.3 (EN/UVLO), U7.26 (GPIO20)
CAM_RST: J4.19, U7.28 (GPIO21)
CSI_D0: J4.6, U7.16 (GPIO11)
CSI_D1: J4.4, U7.18 (GPIO13)
CSI_D2: J4.3, U7.19 (GPIO14)
CSI_D3: J4.5, U7.17 (GPIO12)
CSI_D4: J4.7, U7.15 (GPIO10)
CSI_D5: J4.9, U7.13 (GPIO8)
CSI_D6: J4.11, U7.12 (GPIO7)
CSI_D7: J4.13, U7.10 (GPIO5)
CSI_HSYNC: J4.16, U7.9 (GPIO4)
CSI_MCLK: J4.12, U7.11 (GPIO6)
CSI_PCLK: C46.1, J4.8, U7.14 (GPIO9)
CSI_VSYNC: J4.18, U7.8 (GPIO3)
GND: C1.2, C3.2, C4.2, C5.2, C6.2, C7.1, C8.2, C9.2, C10.1, C11.2, C12.1, C13.1, C14.2, C15.2, C16.2, C17.2, C20.2, C21.2, C22.2, C23.2, C25.2, C26.2, C27.2, C28.2, C29.2, C33.2, C34.2, C37.2, C38.2, C39.2, C40.2, C41.2, C42.2, C43.2, C44.2, C45.2, C46.2, C48.2, C49.2, C50.2, D1.2 (A2), J1.2 (Ext), J2.1, J3.4, J4.10, J4.23, J5.5 (GND), J6.2 (Ext), J7.3, J7.5, J7.7, J7.9, L1.2, R6.1, R10.1, R12.1, R15.1, R24.2, R26.2, R27.1, R32.2, U1.2 (GND), U2.3 (G), U3.1 (GND), U4.1 (GND), U5.4 (GND), U5.11 (GND), U6.1 (A1), U6.2 (A0), U6.7 (GND), U7.57 (GND), U8.4 (GND), U8.9 (GND), U10.4 (GND), U11.4 (VSS), U12.2 (VN), U13.8 (GND), U13.13 (GND), U13.19 (GND), U13.21 (GND), U13.27 (GND), U13.30 (GND), U13.31 (GND), U13.33 (GND), U13.36 (GND), U13.37 (GND), Y2.2, Y2.4
GSM_PWRKEY: U7.37 (GPIO33), U13.39 (~PWRKEY)
GSM_RX: U7.24 (DAC_2), U13.1 (UART1_TXD)
GSM_TX: R23.1, U7.23 (DAC_1)
LED1: R19.1, U7.39 (GPIO35)
LED2: R18.1, U7.38 (GPIO34)
unnamed: C1.1, C2.2, J1.1 (In)
unnamed: C2.1, L1.1, U7.2 (LNA_IN)
unnamed: C11.1, U5.6 (VCC)
unnamed: C13.2, R5.1, Y2.3
unnamed: C18.1, L2.1, U5.2 (SW)
unnamed: C18.2, U5.3 (BST)
unnamed: C19.2, R6.2, R8.1, U5.8 (FB)
unnamed: C27.1, U8.8 (SS)
unnamed: C30.1, U8.6 (COMP)
unnamed: C30.2, R12.2
unnamed: C32.1, L3.1, U8.3 (SW)
unnamed: C32.2, U8.1 (BS)
unnamed: D1.1 (A1), J2.2, U2.1 (D1), U2.2 (D2), U2.5 (D3), U2.6 (D4)
unnamed: D2.1 (K), R18.2
unnamed: D3.1 (K), R19.2
unnamed: J4.17, R27.2
unnamed: J5.2 (RST), R20.1, U12.6 (IO4)
unnamed: J5.3 (CLK), R21.1, U12.1 (IO1)
unnamed: J5.7 (I/O), R22.1, U12.3 (IO2)
unnamed: J6.1 (In), U13.32 (GSM_ANT)
unnamed: Q1.3 (D), R10.2, U8.7 (EN)
unnamed: R1.2, U7.49 (U0RXD)
unnamed: R4.1, U2.4 (S), U6.10 (Vin+)
unnamed: R7.1, U5.5 (PGOOD)
unnamed: R15.2, R16.1, U8.5 (FB)
unnamed: R23.2, R24.1, U13.2 (UART1_RXD)
unnamed: R25.2, R26.1, U13.38 (ADC)
unnamed: R28.2, U7.48 (U0TXD)
unnamed: R32.1, U13.6 (UART1_DTR)
PRGRM: J3.6, R13.1, U7.5 (GPIO0)
PRGR_RX: J3.5, R1.1
PRGR_TX: J3.3, R28.1
RADIO_EN: Q1.1 (G), R9.2, U7.25 (GPIO19)
SCL_AUX: R31.2, U6.5 (SCL), U7.40 (GPIO36)
SCL_CAM: J4.20, R11.2, U7.7 (GPIO2)
SDA_AUX: R30.2, U6.4 (SDA), U7.41 (GPIO37)
SDA_CAM: J4.22, R14.2, U7.6 (GPIO1)
SD_DATA0: U7.36 (SPID), U10.5 (DI(IO0)), U11.5 (SI/SIO)
SD_DATA1: U7.35 (SPIQ), U10.2 (DO(IO1)), U11.2 (SO/SIO)
SD_DATA2: U7.32 (SPIWP), U10.3 (IO2), U11.3 (SIO2)
SD_DATA3: U7.31 (SPIHD), U10.7 (IO3), U11.7 (SIO3)
SIM_CLK: R21.2, U13.16 (SIM_CLK)
SIM_IO: C42.1, R22.2, U13.15 (SIM_DATA)
SIM_RST: R20.2, U13.17 (SIM_RST)
SPICLK: U7.34 (SPICLK), U10.6 (CLK), U11.6 (SCLK)
SPICS0: R29.1, U7.33 (SPICS0), U10.1 (~CS)
SPICS1: R17.1, U7.29 (SPICS1), U11.1 (~CE)
TCK: J7.4, U7.43 (MTCK)
TDI: J7.8, U7.46 (MTDI)
TDO: J7.6, U7.44 (MTD0)
TMS: J7.2, U7.47 (MTMS)
VDD_SDIO: C14.1, C34.1, R17.2, R29.2, U7.30 (VDD_SPI), U10.8 (VCC), U11.8 (VCC)
VSIM: C43.1, J5.1 (VCC), U12.5 (VP), U13.18 (SIM_VDD)
VSUPPLY: C5.1, C6.1, C22.1, R4.2, U5.1 (VIN), U5.7 (RUN), U5.10 (MODE), U6.8 (Vbus), U6.9 (Vin-), U8.2 (IN)
~RST: C39.1, J3.1, R2.2, U7.56 (CHIP_PU)

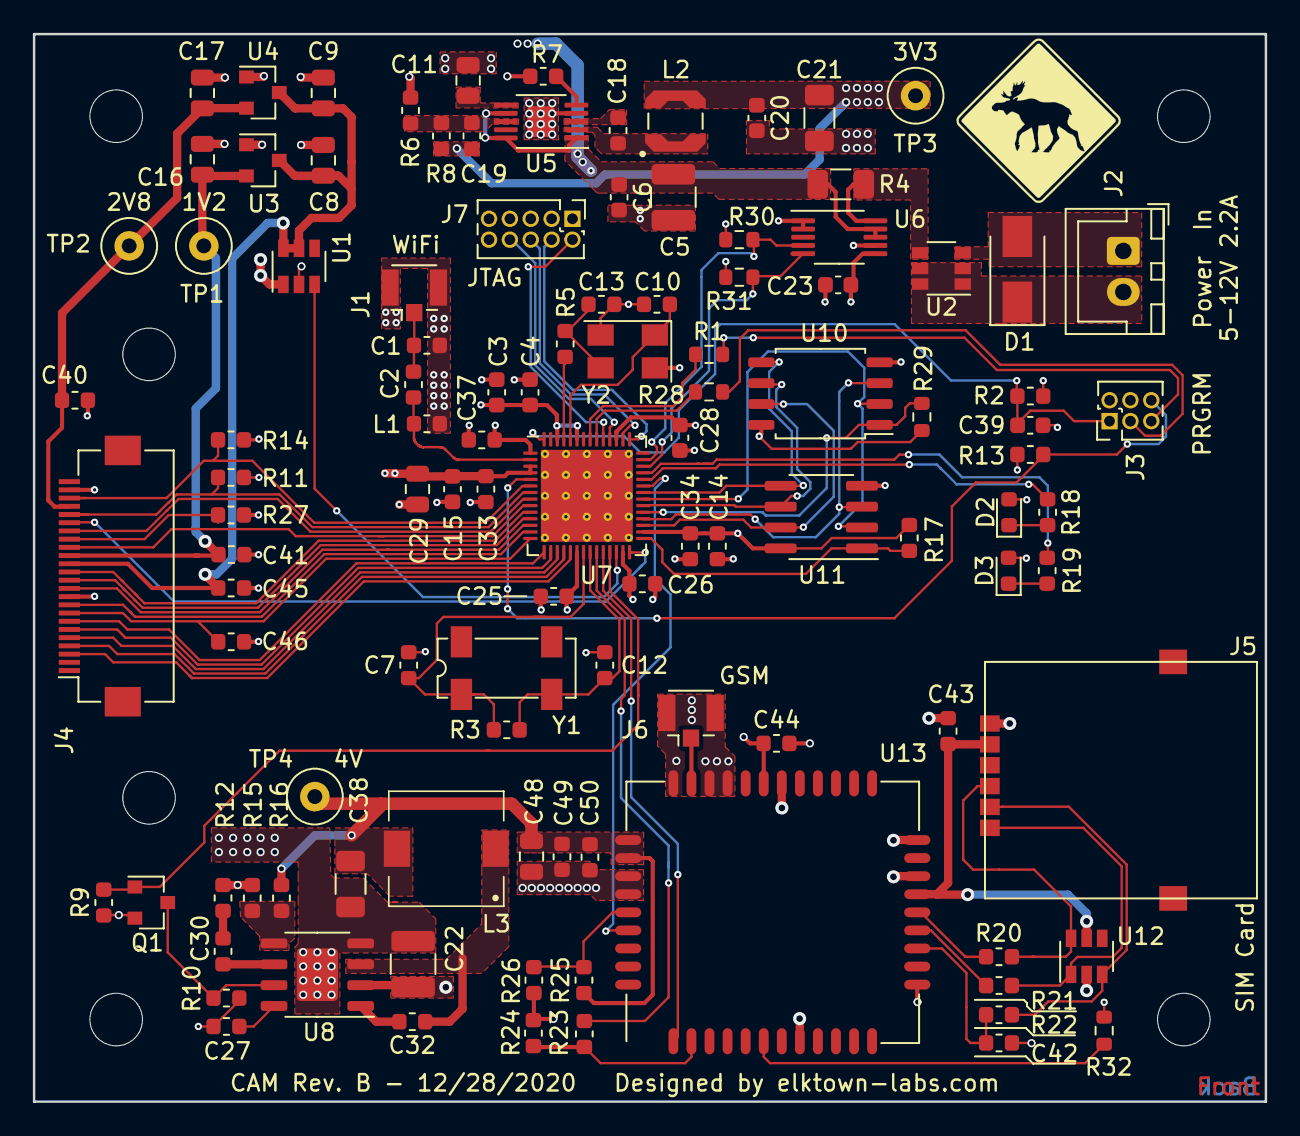
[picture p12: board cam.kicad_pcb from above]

Board: 4 copper layers, 75.0 x 65.0 mm, 109 parts (0 on the bottom side), 84 nets.

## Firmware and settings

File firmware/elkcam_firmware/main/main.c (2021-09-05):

/* Hello World Example

   This example code is in the Public Domain (or CC0 licensed, at your option.)

   Unless required by applicable law or agreed to in writing, this
   software is distributed on an "AS IS" BASIS, WITHOUT WARRANTIES OR
   CONDITIONS OF ANY KIND, either express or implied.
*/
#include <stdio.h>
#include "sdkconfig.h"
#include "freertos/FreeRTOS.h"
#include "freertos/task.h"
#include "freertos/semphr.h"
#include "esp_system.h"
#include "esp_spi_flash.h"
#include "driver/i2c.h"
#include "driver/ledc.h"
#include "esp_wifi.h"
#include "esp_netif.h"
#include "esp_sleep.h"
#include "nvs_flash.h"
#include "esp_event_base.h"
#include "ina226.h"
#include "config.h"
#include "esp_log.h"
#include "wifi.h"
#include "webserver.h"
#include "events.h"
#include "gpios.h"
#include "cellmodem.h"
#include "httpclient.h"
#include "camhandler.h"
#include "cam.h"
#include "configstorage.h"


#define MODE_CONFIG 1
#define MODE_NORMAL 0

ESP_EVENT_DEFINE_BASE(EVENT_BASE);

/* all data to be sent to the server is collected here */
https_upload_t upload_data;

static const char* TAG = "main";

static int transient_sleep_time = 0;
static xQueueHandle sm_uploadeComplete = 0x00;

static void on_ip_connected(void *arg, esp_event_base_t event_base,
                      int32_t event_id, void *event_data)
{
    ESP_LOGI(TAG, "IP connection established");
    https_upload(&upload_data);
}


static void on_set_transient_sleep(void* handler_args, esp_event_base_t base, int32_t id, void* event_data)
{
    transient_sleep_time =  *((int*)event_data);
    ESP_LOGI(TAG, "Received transient sleep time from server: %d", transient_sleep_time);
}


static void on_transfer_done(void* handler_args, esp_event_base_t base, int32_t id, void* event_data)
{
    ESP_LOGI(TAG, "Transfer to server has finished");
    /* unblock main task */
    xSemaphoreGive(sm_uploadeComplete);
}


void boot_msg()
{
    ESP_LOGI(TAG, "ElkCam Firmware V%s, %s Copyright 2021 Elktown Labs.", ELKCAM_SW_VERSION, ELKCAM_SW_DATE);
    ESP_LOGI(TAG, "Booting ESP32S2 / FreeRTOS");

    /* Print chip information */
    esp_chip_info_t chip_info;
    esp_chip_info(&chip_info);
    ESP_LOGI(TAG, "This is %s chip with %d CPU cores, WiFi%s%s, ",
            CONFIG_IDF_TARGET,
            chip_info.cores,
            (chip_info.features & CHIP_FEATURE_BT) ? "/BT" : "",
            (chip_info.features & CHIP_FEATURE_BLE) ? "/BLE" : "");

    ESP_LOGI(TAG, "silicon revision %d, ", chip_info.revision);

    ESP_LOGI(TAG, "%dMB %s flash", spi_flash_get_chip_size() / (1024 * 1024),
            (chip_info.features & CHIP_FEATURE_EMB_FLASH) ? "embedded" : "external");

    ESP_LOGI(TAG, "Free heap: %d", esp_get_free_heap_size());
}


void init_nvs(void)
{
    //Initialize NVS
    esp_err_t ret = nvs_flash_init();
    if (ret == ESP_ERR_NVS_NO_FREE_PAGES || ret == ESP_ERR_NVS_NEW_VERSION_FOUND) {
      ESP_ERROR_CHECK(nvs_flash_erase());
      ret = nvs_flash_init();
    }
    ESP_ERROR_CHECK(ret);
}


void init_event_loop(void)
{
    esp_err_t err = esp_event_loop_create_default();
    if (err != ESP_OK)
    {
        ESP_LOGE(TAG, "Event loop could not be initialized: %d", err);
        return;
    }
    ESP_ERROR_CHECK(esp_event_handler_instance_register(EVENT_BASE, EVENT_TRANSIENT_SLEEP_COMMAND_RECEIVED, on_set_transient_sleep, NULL, NULL));
    ESP_ERROR_CHECK(esp_event_handler_instance_register(EVENT_BASE, EVENT_TRANSFER_DONE, on_transfer_done, NULL, NULL));
    ESP_ERROR_CHECK(esp_event_handler_instance_register(IP_EVENT, IP_EVENT_PPP_GOT_IP, &on_ip_connected, NULL, NULL));
    ESP_LOGI(TAG, "Event loop initialized");
}


int check_for_config_mode(void)
{
    nvs_handle_t handle;
    esp_err_t err;
    int selected_mode = MODE_NORMAL;

    err = nvs_open("cam", NVS_READWRITE, &handle);
    if (err != ESP_OK) {
        ESP_LOGE(TAG, "Error opening nvs config storage (%d)", err);
        goto EXIT;
    }

    /* determine wakeup cause */
    esp_sleep_wakeup_cause_t wakeup_cause = esp_sleep_get_wakeup_cause();
    ESP_LOGI(TAG, "Cause of wakeup: %i", wakeup_cause);
    if (wakeup_cause == ESP_SLEEP_WAKEUP_UNDEFINED) {
        /* this is no wakeup, most likely power was turned on */

        /* get current status of config mode */
        uint8_t enter_config_mode = 0;
        nvs_get_u8(handle, "ENTER_CFG", &enter_config_mode);
        if (enter_config_mode) {
            nvs_set_u8(handle, "ENTER_CFG", 0);
            nvs_commit(handle);
            selected_mode = MODE_CONFIG;
            goto EXIT;
        } else {
            /* wait for 2 sec, the set a nvs variable. If power is turned off when the
                blue led is on, config mode will be entered next time the device  is
                powered up */
            vTaskDelay(2000 / portTICK_PERIOD_MS);
            switch_led(CAM_LED_BLUE, 1);
            nvs_set_u8(handle, "ENTER_CFG", 1);
            nvs_commit(handle);
            vTaskDelay(1000 / portTICK_PERIOD_MS);
            switch_led(CAM_LED_BLUE, 0);
            nvs_set_u8(handle, "ENTER_CFG", 0);
            nvs_commit(handle);
            selected_mode = MODE_NORMAL;
            goto EXIT;
        }
    } else {
        /* this is a wakeup. Go into normal mode */
        nvs_set_u8(handle, "ENTER_CFG", 0);
        nvs_commit(handle);
        selected_mode = MODE_NORMAL;
        goto EXIT;
    }

EXIT:
    nvs_close(handle);
    return selected_mode;
}


int check_voltage()
{
    system_config_t* system_config = config_system();
    double vsupply;

    esp_err_t err = ina226_get_startup_values(&vsupply, 0x00, 0x00, 0x00);
    if (err == ESP_OK) {
        /* voltage */
        if (vsupply * 1000 >= (double)system_config->min_voltage) {
            ESP_LOGI(TAG, "Supply voltage currently at: %.4fmV. We need at least %dmV to continue.",
                vsupply * 1000.0, system_config->min_voltage);
            return pdTRUE;
        } else {
            ESP_LOGE(TAG, "Supply voltage currently at: %.4fmV. We need at least %dmV to continue.",
                vsupply * 1000.0, system_config->min_voltage);
            return pdFALSE;
        }
    } else {
        ESP_LOGE(TAG, "Voltages could not be read from sensor (%x)", err);
        return pdFALSE;
    }
}


void app_main(void)
{
    boot_msg();
    ina226_init();
    init_event_loop();
    init_nvs();
    init_gpios();
    config_load_values();

    int startup_mode = check_for_config_mode();

    if (startup_mode == MODE_NORMAL) {

        /* make sure voltage is above minimum to not damage battery */
        if (!check_voltage()) {
            /* power down ina226 */
            ina226_mode_shutdown();

            /* go to sleep for 1h */
            ESP_LOGE(TAG, "Going to sleep for one hour.");
            uint64_t time_to_sleep = (60u * 60u * 1000u * 1000u); /* 1 h */
            esp_sleep_enable_timer_wakeup(time_to_sleep);
            esp_deep_sleep_start();
        }

        /* create the semaphore for waiting until upload to server is complete */
        sm_uploadeComplete = xSemaphoreCreateBinary();

        /* try to take a picture */
        ESP_LOGI(TAG, "Starting up in regular single picture mode");
        init_cam();
        switch_led(CAM_LED_BLUE, 1);
        reinit_cam();

        for (int i=1; i<5; i++) {
            ESP_LOGI(TAG, "Taking picture. Try %i of 5", i);
            camhandler_load_config_from_nvs();
            cam_start();
            upload_data.buflen = cam_take(&upload_data.bufptr, 8000 / portTICK_PERIOD_MS);
            if (upload_data.buflen == 0) {
                ESP_LOGE(TAG, "Camera timed out");
                upload_data.error = 1;
                reinit_cam();
            } else {
                /* find end of jpeg stream and truncate data there */
                for (uint32_t i=0; i<upload_data.buflen-1; i++) {
                    if (upload_data.bufptr[i] == 0xff && upload_data.bufptr[i+1] == 0xd9) {
                        ESP_LOGI(TAG, "Shortened data from %d to %d.", upload_data.buflen, i+2);
                        upload_data.buflen = i+2;
                        break;
                    }
                }
                ESP_LOGI(TAG, "Picture taken. Size = %d", upload_data.buflen);
                upload_data.error = 0;
                break;
            }
        }
        switch_led(CAM_LED_BLUE, 0);
        ESP_LOGI(TAG, "Shutting down and switching off camera");
        cam_stop();
        shutdown_cam();

        /* increase photo counter */
        if (upload_data.error == 0) {
            system_config_t sys_conf = *(config_system());
            sys_conf.photo_counter++;
            config_write_values(&sys_conf, 0x00, 0x00);
        }

        /* upload to server */
        ESP_LOGI(TAG, "Uploading picture to server");
        ESP_LOGI(TAG, "Power down modem for 2s");
        power_radio(0);
        vTaskDelay(2000 / portTICK_PERIOD_MS);
        ESP_LOGI(TAG, "Power up modem");
        power_radio(1);
        vTaskDelay(500 / portTICK_PERIOD_MS);
        ESP_LOGI(TAG, "Power key on for 1.2s");
        powerkey_radio(1);
        vTaskDelay(1200 / portTICK_PERIOD_MS);
        ESP_LOGI(TAG, "Power key off and wait 1s");
        powerkey_radio(0);
        vTaskDelay(1000 / portTICK_PERIOD_MS);
        ESP_LOGI(TAG, "Init modem");
        cell_config_t cell_conf = *(config_cell());
        bool modemInitSuccessful = init_cellmodem(&cell_conf);

        // only if connection was successful
        if (modemInitSuccessful) {
            int uploadFinished = 0;
            for (int i=0; i<CAM_UPLOAD_TIMEOUT; i++) {
                /* wait until upload to server is done */
                if( xSemaphoreTake(sm_uploadeComplete, pdMS_TO_TICKS(1000)) == pdTRUE ) {
                    ESP_LOGI(TAG, "Upload has finished. Shutting everything down.");
                    uploadFinished = 1;
                    break;
                } else {
                    ESP_LOGI(TAG, "Upload not yet finished. Retrying.");
                }
            }
            if (!uploadFinished) {
                ESP_LOGI(TAG, "Unable to upload. Something went wrong with the modem");
            }
        }

        /* deinitialize stuff */
        cam_give(upload_data.bufptr);

        /* tear down connection */
        ESP_LOGI(TAG, "Closing modem connection");
        if (modemInitSuccessful) close_cellmodem();

        /* power down modem */
        ESP_LOGI(TAG, "Modem power key on for 1.2s");
        powerkey_radio(1);
        vTaskDelay(1200 / portTICK_PERIOD_MS);
        ESP_LOGI(TAG, "Modem power key off and wait 1s");
        powerkey_radio(0);
        vTaskDelay(1000 / portTICK_PERIOD_MS);
        ESP_LOGI(TAG, "Power down modem now");
        power_radio(0);

        /* power down ina226 */
        ina226_mode_shutdown();

        /* figure out sleep time */
        uint32_t sleep_time = 0;
        if (transient_sleep_time > 0) {
            /* we have received a transient sleep time from server */
            sleep_time = transient_sleep_time;
            ESP_LOGI(TAG, "Using transient sleep time of %d secs", sleep_time);
        } else {
            /* use normal sleep time */
            sleep_time = config_system()->secs_between_photos;
            ESP_LOGI(TAG, "Using sleep time from config: %d secs", sleep_time);
        }

        /* go back to sleep */
        TickType_t timeAlive = xTaskGetTickCount() * portTICK_PERIOD_MS;
        unsigned long long actual_time_to_sleep = (sleep_time * 1000);
        if (actual_time_to_sleep > timeAlive) {
            /* substract the time we've been awake from the time we want to sleep. This helps */
            /* to keep the time between photos roughly equal */
            actual_time_to_sleep -= timeAlive;
        } else {
            /* we were alive longer than we are supposed to sleep. Sleep for the minimum time allowed */
            ESP_LOGI(TAG, "Alive for %d ms which is longer than supposed %u ms sleep time. Sleeping for minimum time of %u ms",
                timeAlive, sleep_time, CAM_MINIMUM_SLEEP_TIME);
            actual_time_to_sleep = CAM_MINIMUM_SLEEP_TIME;
        }
        /* make sure we sleep for a minimum time between photos */
        if (actual_time_to_sleep < CAM_MINIMUM_SLEEP_TIME) {
            ESP_LOGI(TAG, "Time to sleep determined to be %llu ms. Need to sleep at least %u ms",
                actual_time_to_sleep, CAM_MINIMUM_SLEEP_TIME);
            actual_time_to_sleep = CAM_MINIMUM_SLEEP_TIME;
        }
        ESP_LOGI(TAG, "Up for %d ms. Going to sleep for %llu ms", timeAlive, actual_time_to_sleep);
        esp_sleep_enable_timer_wakeup(actual_time_to_sleep * (unsigned long long)1000);
        esp_deep_sleep_start();

    } else if (startup_mode == MODE_CONFIG) {

        init_wifi();
        init_cam();
        start_webserver();

        uint8_t led_state = 0;
        for (;;) {
            vTaskDelay(1000 / portTICK_PERIOD_MS);
            /* blink led to signal config mode */
            switch_led(CAM_LED_BLUE, led_state);
            led_state = ~led_state;
        }
    }

}

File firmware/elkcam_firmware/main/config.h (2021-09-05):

#ifndef _CONFIG_H_
#define _CONFIG_H_

#define ELKCAM_SW_VERSION "1.1.0"
#define ELKCAM_SW_DATE "07/24/2021"

/* wifi */
#define CAM_CONFIG_SSID "elkcam"

/* minimum sleep time between photos in ms */
#define CAM_MINIMUM_SLEEP_TIME (60000)

/* camera settle time after changing settings in ms*/
#define CAM_SETTLE_TIME (4000)

/* time to allow for the upload to finish in secs */
#define CAM_UPLOAD_TIMEOUT (10*60)

/* default picture settings */
#define CAM_DEFAULT_QUALITY (10)  /* 0 - 63 */
#define CAM_DEFAULT_AUTO_EXPOSURE (2)
#define CAM_DEFAULT_LIGHT_MODE (0)
#define CAM_DEFAULT_COLOR_SATURATION (0)
#define CAM_DEFAULT_PIXELTIMING (0)
#define CAM_DEFAULT_BRIGHTNESS (0)
#define CAM_DEFAULT_CONTRAST (0)
#define CAM_DEFAULT_HUE (0)
#define CAM_DEFAULT_SHARPNESS (0)

/* default cell service settings */
#define CAM_CELL_PIN "6400"
#define CAM_CELL_APN "internet.telekom"
#define CAM_CELL_APN_USER "congstar"
#define CAM_CELL_APN_PASS "cs"
#define CAM_CELL_APN_AUTH 0x01 /*PAP*/
#define CAM_CELL_REMOTE_ADDRESS "wwv-schwarzwald.de"
#define CAM_CELL_REMOTE_URL "https://wwv-schwarzwald.de/webcam/api/upload"

/* default system settings */
#define SYS_DEFAULT_SECS_BETWEEN_PHOTOS (30*60)
#define SYS_DEFAULT_MIN_VOLTAGE (10300) /* 10.3V (10.4V for LiFePo4 and some margin for measuring errors) */


#endif

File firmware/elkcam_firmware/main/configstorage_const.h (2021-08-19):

#ifndef _CONFIGSTORAGE_CONST_H_
#define _CONFIGSTORAGE_CONST_H_

/* jpeg storage quality, integer 0 - 63 */
#define CONFIGSTORAGE_KEY_CAM_QUALITY "cam_quality"

/* camera auto exposure setting, integer 0 - 4 */
#define CONFIGSTORAGE_KEY_CAM_AUTO_EXPOSURE "cam_exposure"

/* camera light mode, integer 0 - 4 */
/* 0: auto, 1: sunny, 2: cloudy, 3: office, 4: home */
#define CONFIGSTORAGE_KEY_CAM_LIGHT_MODE "cam_light"

/* camera color saturation, integer 0 - 4 */
/* 0: -2, 1: -1, 2:  0, 3: +1, 4: +2 */
#define CONFIGSTORAGE_KEY_CAM_COLOR_SATURATION "cam_col_sat"

/* camera pixel clock divider */
/* 0 - 0x0e */
#define CONFIGSTORAGE_KEY_CAM_PIXELTIMING "cam_pixtiming"

/* camera brightness, integer 0 - 4 */
/* 0: -2, 1: -1, 2:  0, 3: +1, 4: +2 */
#define CONFIGSTORAGE_KEY_CAM_BRIGHTNESS "cam_brightnss"

/* camera contrast, integer 0 - 4 */
/* 0: -2, 1: -1, 2:  0, 3: +1, 4: +2 */
#define CONFIGSTORAGE_KEY_CAM_CONTRAST "cam_contrast"

/* camera contrast, integer 0 - 4 */
/* 0: -2, 1: -1, 2:  0, 3: +1, 4: +2 */
#define CONFIGSTORAGE_KEY_CAM_HUE "cam_hue"

/* camera contrast, integer 0 - 4 */
/* 0: -2, 1: -1, 2:  0, 3: +1, 4: +2 */
#define CONFIGSTORAGE_KEY_CAM_SHARPNESS "cam_sharpness"

/* cell phone pin, string */
/* can be set to an arbitary string if no pin is required by sim */
#define CONFIGSTORAGE_KEY_CELL_PIN "cell_pin"

/* cell phone data access apn, string */
#define CONFIGSTORAGE_KEY_CELL_APN "cell_apn"

/* cell phone apn user name, string */
/* can be set to an arbitary value if no user name is required and */
/* CONFIGSTORAGE_KEY_CELL_APN_AUTH is 0 */
#define CONFIGSTORAGE_KEY_CELL_APN_USER "cell_apn_user"

/* cell phone apn password, string */
/* can be set to an arbitary value if no password is required and */
/* CONFIGSTORAGE_KEY_CELL_APN_AUTH is 0 */
#define CONFIGSTORAGE_KEY_CELL_APN_PASS "cell_apn_pass"

/* apn authentication required by operator, integer 0 - 1 */
#define CONFIGSTORAGE_KEY_CELL_APN_AUTH "cell_apn_auth"

/* remote host name, sent in http host reader, string */
#define CONFIGSTORAGE_KEY_CELL_REMOTE_ADDRESS "cell_rem_adr"

/* complete remote url, used to access the upload facility, string */
#define CONFIGSTORAGE_KEY_CELL_REMOTE_URL "cell_rem_url"

/* default time between photos in seconds. Can be temporarily overwritten */
/* by server, integer */
#define CONFIGSTORAGE_KEY_SYS_SECS_BETWEEN_PHOTOS "sys_t_btw_phts"

/* default minimum voltage when photos are no longer taken */
#define CONFIGSTORAGE_KEY_SYS_MIN_VOLTAGE "sys_min_v"


/* photos taken. This cannot be reset by firmware, integer */
#define CONFIGSTORAGE_KEY_SYS_PHOTO_COUNTER "sys_p_counter"

#endif

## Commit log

2020-12-27 Finished PCB for ESP32-S2
    [cam.kicad_pcb, cam.sch]
2020-12-27 Minor fixed to ESP-S2 pcb
    [cam.kicad_pcb]
2020-12-27 More optimizations to pcb
    [cam.kicad_pcb]
2020-12-27 Fixed connection / layout of flash / ram chips
    [cam.kicad_pcb, cam.sch]
2020-12-28 More fixes to pcb
    [cam.kicad_pcb]
2021-01-26 Finished revision 1
    [bom.ods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]
2021-03-17 Added BOM sheet for manual population; Updated PCB
    [bom.ods, cam.kicad_pcb]
2021-04-04 finished pcb revision b
    [bom.ods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]
2021-04-04 Small changes to pcb
    [cam.kicad_pcb]
2021-04-04 Added 3D model for possible lens holder
    [lens_holder.fcstd]
2021-04-04 Deleted old pcb; renamed discrete esp-s2 pcb to pcb
    [bom.ods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]
2021-04-04 Fixed length of nvs keys; fixed wrong 'firmware' json key
    [configstorage_const.h]
2021-04-12 Added error-handling and retried for camera handling
    [cam.c, config.h, main.c]
2021-04-13 Added draft html page for esp32 web frontend
2021-04-14 Added cad parts and web frontend
    [BOLTS.scad, BOLTS_ANSI.scad, BOLTS_ASME.scad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]
2021-04-14 added cad libraries
2021-04-17 Fixed camera settings; Added hue and saturation settings
    [config.h, configstorage_const.h, main.c]
2021-04-24 Upped version to 0.0.3; Added current settings to json sent to server
2021-05-01 Changed 3d model for camera holder
    [ov2640_holder.scad]
2021-05-02 Completed camera settings interface
2021-06-07 Firmware: Many fixes. Camera more stable; Modem more stable
    [cellmodem.c, esp_modem.c]
2021-07-09 Firmware: Fixed camera access
2021-07-22 Config mode can now be reached by turning off power at a certain time
2021-07-23 Fixed software version information
    [config.h, main.c]
2021-07-24 renamed user db to settings db; added camera settings to db; added full name to json return structure of authenticate.php
2021-07-24 Url now taken from config and no longer hardcoded; partition for firmware now 4MB
    [partitions.csv]
2021-07-27 Added pixel timing function for exposure control; Fixed PAP/CHAP mixup in web-ui
    [config.h, configstorage_const.h, main.c]
2021-08-19 Added narrow base for battery and camera
    [BOLTS.scad, BOLTS_ANSI.scad, BOLTS_ASME.scad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]
2021-08-19 Added minimum voltage check on startup
2021-09-02 Vue frontend: Small device app nav menu now hides options the user has no rights for.
2021-09-03 Web-Backend: Added cleanup script for linux and systemd service/timer definitions
2021-09-03 Updated .env.* to reflect current api locations
2021-09-05 Firmware: Added camera settle time after cam settings have been modified
2021-09-05 Web Backend: updated directories for production; time-out interval fixed when camera starts to early; upload receiver picture management updated
2021-12-05 Backend: fixed get_frequency: Scheduled mode switch was not shown correctly
2022-06-04 PCB: VSupply track now connects to all supply pins
    [cam.kicad_pcb]
2022-06-04 Removed old, unused 3d drawings
    [lens_holder.fcstd]
2022-06-04 Lots of cleanup; Added bom;
    [BOLTS.scad, BOLTS_ANSI.scad, BOLTS_ASME.scad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]
2022-08-03 PCB: Updated values of some components
    [cam.sch]
2022-11-24 Added infos about the used lens and lens holder
2022-11-25 Added infos about the power source
2022-12-03 Added note about sim cards without a PIN to user interface.
2023-08-24 Migrated to KiCad7
    [cam.kicad_pcb, cam.kicad_sch]
